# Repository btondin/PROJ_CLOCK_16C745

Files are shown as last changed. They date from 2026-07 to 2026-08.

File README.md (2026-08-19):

# VFDCLK — Relógio VFD com PIC16C745

Relógio e termo-higrômetro de bancada baseado no microcontrolador
**PIC16C745** (USB 1.1 nativo). Mostra num display **VFD IEE Century 036X2
(20×2)** a **hora e a data**, alternando com **temperatura e umidade**, e
**acerta o relógio pela porta USB**: basta conectar o dispositivo ao PC e
rodar um pequeno utilitário em Python que envia a hora local — sem
instalar driver (o aparelho enumera como HID genérico).

> Firmware em C (MPLAB XC8), escrito na forma canônica de projetos para
> PIC: `board.h` central, um driver por periférico, documentação e
> referência de datasheet em cada módulo. Compila em **90,6 %** da ROM
> (7423/8192 words) e **96,9 %** da RAM (248/256 bytes) do PIC16C745.

---

## Recursos

- ⏰ **Relógio/calendário** com RTC **DS3231** (±2 ppm, com bateria de
  retenção). Detecta hora inválida (flag OSF) e avisa no display.
- 🌡️ **Temperatura e umidade** com sensor **Sensirion SHT15**, incluindo
  verificação de **CRC-8** e conversão em **ponto fixo** (sem `float`,
  validada contra as fórmulas oficiais da Sensirion).
- 🖥️ **Display VFD 20×2** em modo serial (19200 8N1). A **linha de cima
  é fixa com o horário** e o indicador de alarme; só a **linha de baixo
  alterna** (6 s data / 4 s clima):

  ```
  |      14:35:27     S|      S = sino, só com o alarme ligado
  |   TER 16/07/2026   |   <-> | 23.4 °C     45.2 %RH|
  ```

  As duas linhas são escritas num único fluxo de 40 caracteres
  (auto-wrap), o que mantém a 2ª linha estável sem depender do comando
  de trava de rolagem. Como o relógio fica sempre na mesma posição, a
  atualização por segundo reescreve só o dígito que mudou — sem piscar, e
  isso vale nas duas telas do carrossel.
- 🔔 **Os dois símbolos vêm por caminhos diferentes**:
  - o **grau** é caractere **nativo** da fonte deste módulo (`B9h`), então
    não gasta comando nem slot;
  - o **sino** não existe na fonte, então é desenhado numa matriz 5×7 e
    gravado no charset (`F6h`, comando `18h`) uma vez no boot.
- 🔌 **Acerto de hora por USB** (classe HID, **sem driver**): o firmware
  recebe a hora do PC e grava no DS3231. Todo o stack USB roda por
  interrupção, então o relógio nunca "trava" durante a comunicação.
- ⏱️ **Alarme de despertador, só em DIA ÚTIL** (seg–sex), fixo: é o uso
  real do aparelho e o espaço de programa é curto, então não há opção de
  menu para isso. O horário é configurável pelo PC (`--alarme 07:30`) e
  liga/desliga pelos botões; tudo mora nos registradores do **DS3231
  alimentados pela bateria** — a única memória não-volátil do projeto, já
  que o PIC16C745 é OTP e **não tem EEPROM**. Aviso sonoro (buzzer) +
  mensagem piscando no display; ao tocar, **qualquer botão silencia** (e
  rearma para o dia seguinte).

  > O filtro de dia útil é feito pelo firmware: o DS3231 só sabe casar
  > *um* dia da semana específico, não "seg a sex". Ele dispara todo dia
  > e o firmware, no fim de semana, reconhece o flag em silêncio.

  Ligado ou desligado aparece direto na tela do relógio, na última coluna
  da linha de cima: **sino** ou **nada**.
- 🔘 **Menu de configuração por dois botões**: o **botão 1** abre o menu e
  percorre as opções (**alarme**, **brilho da tela**); o **botão 2** altera
  a opção mostrada — o alarme liga/desliga, e o brilho sobe até o máximo e
  volta ao mínimo. Sem toque por 3 s, o menu fecha e o carrossel volta.
- 🐕 **Watchdog ligado** (~2,3 s): qualquer travamento reinicia o PIC e o
  relógio se recupera sozinho, em vez de ficar mudo. As esperas longas do
  boot são fatiadas com `CLRWDT` (macro `ESPERAR_MS`, em `board.h`), porque
  o pior caso do temporizador do 16C745 é ~0,9 s, não os 2,3 s nominais.
- 💓 **LED de heartbeat** (RA2): pisca a ~1 Hz enquanto o laço roda —
  sinal permanente de que o PIC está vivo, e um diagnóstico grátis (se
  congelar, algo travou). Fica em RA2 (não em RC0) porque o RC0 é o pino
  do Timer1, usado como base de tempo do bipe do alarme.

---

## Estrutura do repositório

```
PROJ_CLOCK_16C745/
├── README.md                 ← este arquivo
├── LICENSE                   ← MIT (código)
├── VFDCLK.X/                 ← projeto MPLAB X (firmware)
│   ├── main.c                ← laço principal e telas
│   ├── board.h               ← mapa de pinos e macros de hardware
│   ├── uart.c/.h             ← USART (serial para o VFD)
│   ├── vfd.c/.h              ← driver do display IEE 036X2
│   ├── swi2c.c/.h            ← mestre I²C por software
│   ├── ds3231.c/.h           ← driver do RTC
│   ├── sht1x.c/.h            ← driver do sensor + conversão ponto fixo
│   ├── usb_hid.c/.h          ← stack USB HID (capítulo 9 + classe)
│   ├── usb_desc.c/.h         ← descritores USB
│   └── botoes.c/.h           ← debounce e toque curto/longo
├── DTCAPP/                   ← utilitário do PC (Python)
│   ├── dtc_sync.py           ← acerta hora e alarme pelo USB
│   ├── teste_conversao.py    ← valida a matemática do SHT15
│   └── requirements.txt
├── HARDWARE/
│   ├── pinagem.md            ← ligação elétrica completa (LEIA-ME)
│   └── VFD_CLOCK.pdsprj      ← simulação em Proteus
└── DOCS/                     ← datasheets (fora do controle de versão)
```

> A pasta `DOCS/` fica **fora do Git** (ver `.gitignore`): o datasheet do
> display IEE é material proprietário e não pode ser redistribuído. Os
> links oficiais estão [na seção de referências](#referências-datasheets).

---

## Hardware

Resumo dos periféricos (detalhes, valores de componentes e esquemático em
[`HARDWARE/pinagem.md`](HARDWARE/pinagem.md)):

| Bloco | Pinos do PIC | Observação |
|---|---|---|
| Display VFD  | RC6/TX (17) | serial 19200 8N1, **via MAX232** |
| RTC DS3231 | RB4/SCL, RB5/SDA, RB0/INT | I²C por software (pull-ups 4,7 kΩ); INT/SQW no INT0 (uso futuro) |
| Sensor SHT15 | RB2/DATA, RB3/SCK | Sensibus, pull-up 10 kΩ em DATA |
| USB | RC4/D-, RC5/D+, VUSB | low-speed, 1,5 kΩ de VUSB para D- |
| Clock | OSC1/OSC2 (9/10) | cristal 24 MHz (HS, sem PLL) |
| Botões | RA0, RA1 (2/3) | menu: navegar / alterar, pull-up 10 kΩ |
| Buzzer | RC2 (13) | alarme, via transistor NPN |
| LED heartbeat| RA2 (4) | liveness ~1 Hz, série c/ 330 Ω |
| Base de tempo| TMR1 (usa RC0) | ritmo do bipe; RC0 fica sem uso externo  |

⚠️ **Ponto de atenção — serial do display:** o VFD espera a linha em
repouso no nível **baixo** (mark, padrão EIA-232), enquanto a UART do PIC
repousa em nível **alto**. Um **MAX232** entre RC6 (T1IN) e a entrada do
display (T1OUT) faz as duas coisas: converte TTL ↔ EIA-232 e inverte a
polaridade. O esquemático completo (canal, capacitores e jumpers do
display) está no documento de hardware.

---

## Compilando o firmware

**Ferramentas** (as mesmas com que o projeto foi validado):

- MPLAB X IDE **v6.30**
- Compilador MPLAB **XC8 v4.00**
- Device Family Pack **PIC12-16Cxxx_DFP 1.7.175**

### Pelo MPLAB X (recomendado)

1. `File → Open Project…` e selecione a pasta `VFDCLK.X`.
2. Clique em **Build** (o martelo). O `.hex` sai em
   `VFDCLK.X/dist/default/production/VFDCLK.X.production.hex`.

### Pela linha de comando

```bash
cd VFDCLK.X
make            # usa os Makefiles do projeto + XC8
```

> É esperado o build emitir avisos `(520) function ... is never called`
> para algumas funções de API dos drivers (ex.: `vfd_limpar`,
> `uart_enviar`): elas fazem parte da biblioteca reutilizável de cada
> módulo, não são usadas por *este* programa e o XC8 as remove do binário
> (garbage collection). O advisory `(1510)` sobre `ep1_armar` também é
> normal — o compilador duplica a função por ela ser chamada tanto pelo
> laço quanto pela interrupção.

### Gravando o PIC16C745

O PIC16C745 é **OTP** (memória EPROM). Para desenvolvimento, use a versão
**/JW** (com janela de quartzo, apagável por UV) e um gravador compatível
(ex.: PICSTART/PICkit com adaptador). Grave o `.hex` gerado acima. Os bits
de configuração já vão embutidos (`FOSC=HS, WDTE=ON, PWRTE=ON, CP=OFF`).

---

## Acertando a hora pelo USB

Com o relógio conectado ao PC (ele aparece como HID, sem driver):

```bash
cd DTCAPP
pip install -r requirements.txt
python dtc_sync.py         # usa a hora deste PC
python dtc_sync.py --ntp   # usa a hora oficial, buscada na internet
```

O utilitário envia a hora local; o firmware grava no DS3231, o display
mostra **"HORA SINCRONIZADA"** e o script lê de volta hora, temperatura
e umidade como confirmação.

Com **`--ntp`** ele consulta antes um servidor de tempo por **SNTP**
(RFC 4330, UDP 123 — padrão `a.ntp.br`/`b.ntp.br` do NIC.br, com
`pool.ntp.org` de reserva; trocável por `--ntp-servidor`). O SNTP mede o
tempo de ida-e-volta do pacote e desconta metade dele, acertando em
milissegundos — muito além do que um RTC de 1 s de resolução precisa, e
melhor que uma API HTTP, cuja latência de requisição vai embutida na
resposta. Não custa dependência nenhuma: só `socket` e `struct` da
biblioteca padrão. O envio é alinhado com a virada do segundo *já
corrigido*, então o DS3231 começa o segundo junto com a fonte oficial.

> O NTP entrega tempo absoluto (UTC); o **fuso** continua vindo da
> configuração do PC. Ou seja: `--ntp` conserta relógio atrasado, não
> fuso horário errado.

No Windows, [`DTCAPP/configurar.bat`](DTCAPP/configurar.bat) dá um menu
(duplo-clique) para sincronizar a hora e configurar o alarme sem digitar
comando nenhum. Detalhes em [`DTCAPP/README.md`](DTCAPP/README.md).

---

## Como funciona (visão geral)

- **Laço principal cooperativo** (`main.c`): a cada ~50 ms lê o DS3231;
  na virada do segundo, redesenha a tela, alterna a linha de baixo entre
  data e clima e, a cada 30 s, dispara uma medição do SHT15. Alimenta o
  watchdog uma vez por volta.
- **USB por interrupção** (`usb_hid.c`): o SIE do PIC16C745 cuida da
  camada física; o firmware trata apenas transações completas (reset,
  enumeração do capítulo 9, classe HID). A troca de dados usa dois
  "correios" protegidos contra concorrência entre a ISR e o laço.
- **Sem `float`**: a conversão do SHT15 usa inteiros de 32 bits com
  coeficientes escalonados; o erro versus as fórmulas oficiais é
  < 0,05 °C / 0,15 %RH, comprovado por `DTCAPP/teste_conversao.py`.
- **Pilha de hardware de 8 níveis**: é o recurso mais escasso do projeto e
  a origem do bug mais difícil que ele teve. Ela é **circular e não detecta
  estouro**: passando de 8, o endereço de retorno mais antigo é sobrescrito
  em silêncio e o PIC volta para lixo. Com `_main` exigindo 8 e a ISR do USB
  exigindo 3, bastava a interrupção cair no ponto mais fundo para o firmware
  sumir — sem display e sem heartbeat. Como depende do instante da
  interrupção, o defeito era uma **corrida**: builds quase idênticos ora
  rodavam, ora não.

  A cadeia foi encurtada para **7 de 8** eliminando chamadas escondidas de
  biblioteca no caminho mais fundo: divisões e multiplicações em `por_decimos`
  e `vfd_campo_bcd` (que viravam `___lwdiv`/`___lwmod`/`___bmul`) e funções
  intermediárias de uma linha só. Confira o orçamento sempre que mexer no
  código, com:

  ```bash
  grep -B2 "Hardware stack levels required" VFDCLK.X/dist/default/production/VFDCLK.X.production.lst
  ```

  Se `_main` voltar a 8, o firmware pode parar de dar boot sem nenhuma outra
  pista. Os módulos são deliberadamente "achatados" por esse motivo — ver
  também a nota no cabeçalho de `usb_hid.c`.

---

## Referências (datasheets)

Documentos oficiais usados no projeto (baixe direto do fabricante):

- **PIC16C745/765** — Microchip, doc. *DS41124* →
  <https://www.microchip.com/en-us/product/PIC16C745>
- **DS3231** — Analog Devices (Maxim) →
  <https://www.analog.com/en/products/ds3231.html>
- **SHT1x / SHT15** — Sensirion (datasheet, *Sample Code* e *CRC
  Calculation*) →
  <https://sensirion.com/products/catalog/SHT15>
- **Display VFD IEE Century 036X2** — Industrial Electronic Engineers,
  *Product Specification S036X2* (documento proprietário; solicite ao
  fabricante) → <https://www.ieeinc.com/>

---

## Nota sobre o VID/PID USB

O firmware usa o par de **teste** do projeto [pid.codes](https://pid.codes)
(**VID 0x1209 / PID 0x0001**), adequado para desenvolvimento e uso
pessoal. Para distribuir um produto, solicite um PID próprio — nunca
reutilize o VID/PID de outro fabricante.

---

## Licença

Código sob licença **MIT** (ver [LICENSE](LICENSE)). A licença cobre o
firmware e o utilitário do PC; **não** se estende aos datasheets dos
fabricantes nem ao protocolo proprietário do display IEE.

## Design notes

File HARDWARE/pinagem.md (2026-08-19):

11não# Hardware — Relógio VFD (PIC16C745)

Documento de ligação elétrica do projeto. A pinagem do MCU foi conferida
contra o arquivo de definição oficial do dispositivo (Microchip DFP
`PIC16C745.PIC`) e o datasheet DS41124D.

> A simulação em Proteus está em [`VFD_CLOCK.pdsprj`](VFD_CLOCK.pdsprj)
> (abrir com o Proteus 8). Ela reproduz a fiação descrita abaixo.

---

## 1. Pinagem do PIC16C745 (encapsulamento DIP-28 / SOIC-28)

```
                    ┌───────────────┐
        MCLR/VPP  1 ┤●              ├ 28  RB7/ICSPDAT
         RA0/AN0  2 ┤ ── BOTÃO 1    ├ 27  RB6/ICSPCLK
         RA1/AN1  3 ┤ ── BOTÃO 2    ├ 26  RB5   ── SDA  (DS3231)
         RA2/AN2  4 ┤ ── LED (HB)   ├ 25  RB4   ── SCL  (DS3231)
    RA3/AN3/VREF  5 ┤               ├ 24  RB3   ── SCK  (SHT15)
     RA4/T0CKI    6 ┤               ├ 23  RB2   ── DATA (SHT15)
        RA5/AN4   7 ┤   PIC16C745   ├ 22  RB1   (livre)
            VSS   8 ┤   (GND)       ├ 21  RB0   ── INT/SQW (DS3231)
      OSC1/CLKIN  9 ┤   ── xtal     ├ 20  VDD   (+5 V)
     OSC2/CLKOUT 10 ┤   ── xtal     ├ 19  VSS   (GND)
   RC0/T1OSO     11 ┤ (TMR1, livre) ├ 18  RC7/RX/DT
   RC1/T1OSI     12 ┤               ├ 17  RC6/TX ── serial p/ VFD (via MAX232)
      RC2/CCP1   13 ┤ ── BUZZER     ├ 16  RC5/D+ ── USB D+
           VUSB  14 ┤               ├ 15  RC4/D- ── USB D-
                    └───────────────┘
```

| Pino | Sinal | Ligação no projeto |
|-----:|---|---|
| 1  | MCLR/VPP | Pull-up 10 kΩ para +5 V (+ conector ICSP p/ gravar) |
| 2  | RA0 | **Botão 1** (navegar no menu) — p/ GND, pull-up 10 kΩ |
| 3  | RA1 | **Botão 2** (alterar opção) — p/ GND, pull-up 10 kΩ |
| 4  | RA2 | **LED de heartbeat** — em série c/ ~330 Ω para GND |
|  11  | RC0 | **Sem ligação externa** — é T1OSO/T1CKI, usado pelo TMR1 internamente (base de tempo do bipe do alarme); não usar como I/O |
|  13  | RC2 | **Buzzer** via transistor NPN (nível 1 = tocando) |
| 8  | VSS | GND |
| 9  | OSC1 | Cristal 24 MHz + 15–22 pF para GND |
|  10  | OSC2 | Cristal 24 MHz + 15–22 pF para GND |
|  14  | VUSB | Capacitor de 0,22 µF para GND; **1,5 kΩ p/ D‑ (pino 15)** |
|  15  | RC4/D- | USB D- (verde) |
|  16  | RC5/D+ | USB D+ (branco) |
|  17  | RC6/TX | Entrada serial do VFD (J1-14) **via MAX232** (T1IN, pino 11)  |
|  19  | VSS | GND |
|  20  | VDD | +5 V |
|  21  | RB0/INT | **INT/SQW do DS3231** (dreno aberto, pull-up 4,7 kΩ; entrada INT0 — **uso futuro**) |
|  22  | RB1 | Livre |
|  23  | RB2/DATA | DATA do SHT15 (pull-up 10 kΩ para +5 V) |
|  24  | RB3/SCK | SCK do SHT15 |
|  25  | RB4/SCL | SCL do DS3231 (pull-up 4,7 kΩ para +5 V) |
|  26  | RB5/SDA | SDA do DS3231 (pull-up 4,7 kΩ para +5 V) |
| 27/28| RB6/RB7 | ICSPCLK/ICSPDAT (gravação in-circuit) |

O pino RB1 fica livre (RB6/RB7 são reservados ao ICSP de gravação).

---

## 2. Alimentação e oscilador

- **+5 V / GND**: VDD no pino 20, VSS nos pinos 8 e 19 (ligar ambos!).
  Capacitor de desacoplamento de 100 nF junto a cada par VDD/VSS.
- **Cristal**: 24 MHz entre OSC1 (9) e OSC2 (10), com dois capacitores de
  carga (15–22 pF) de cada pino para GND, em modo HS (bit de configuração
  `FOSC = HS`). Os 24 MHz são exigidos diretamente pelo USB (sem PLL).
  Não use ressonador de baixa precisão: o USB exige ±0,25 % de tolerância.

---

## 3. USB (low-speed)

O PIC16C745 tem transceptor e regulador de 3,3 V embutidos.

```
   Conector USB          PIC16C745
   ─────────────         ─────────────
   VBUS (+5V) ───────────► VDD (20)   (se alimentado pelo barramento)
   D-         ───────────► RC4/D- (15)
   D+         ───────────► RC5/D+ (16)
   GND        ───────────► VSS (8,19)

   VUSB (14) ──┬── 0,22 µF ── GND
               └── 1,5 kΩ ──► D- (15)     ◄── identifica LOW-SPEED
```

- O resistor de **1,5 kΩ de VUSB (3,3 V) para D‑** é o que faz o host
  reconhecer um dispositivo **low-speed** (o firmware liga o VUSB via
  `UCTRL.DEV_ATT` em `usb_iniciar()`).
- Alimentação: o projeto declara-se **self-powered** (descritor,
  `bMaxPower = 20 mA`). Se preferir alimentar pelo próprio USB
  (bus-powered), ligue VBUS ao VDD e troque `bmAttributes` para 0x80 no
  `usb_desc.c` — mas cuidado com o limite de corrente do VFD (o display
  consome bem mais que 100 mA e deve ter fonte própria de qualquer modo).

---

## 4. Serial para o display VFD (o ponto que exige atenção)

O display **IEE 036X2** é usado em **modo serial** (19200 8N1). Ajuste os
jumpers de "personalidade" da placa do display para **19200 baud** e
partida **NORM**, mantendo o **conjunto de comandos nativo (Intel, que é o
padrão)** — **não** selecione o modo **LCD** (ele troca os comandos para os
do HD44780, e o firmware usa os códigos nativos IEE). Seção 3.2.3 do
datasheet do display.

### Por que um MAX232 (conversão de nível + inversão de polaridade)

O datasheet do display (seção 3.2.2.1) especifica a entrada serial em
níveis **EIA-232**, com a linha em **repouso no nível baixo (mark)**:

| Nível lógico | Tensão EIA-232 | Estado de repouso |
|---|---|---|
| space (logic 0 / start) | +3 a +15 V | |
| mark  (logic 1 / idle) | −3 a −15 V | **repouso = mark**|

A UART do PIC (RC6/TX) faz o oposto: repousa em **nível alto** (idle = 5 V)
e o PIC16C745 **não** inverte por hardware. O **MAX232 resolve as duas
coisas ao mesmo tempo**, pois é um driver **inversor** *e* conversor de
nível:

- converte TTL (0/5 V) → EIA-232 real (±~8 V); e
- inverte a polaridade que o display espera:
  - RC6 em repouso **alto** (mark)  → T1OUT **negativo** = mark ✔
  - RC6 em **start** baixo (space)  → T1OUT **positivo** = space ✔

Como só transmitimos para o display, usa-se **um único canal (T1)**:

```
   PIC RC6/TX (17) ──► T1IN (11)   MAX232   T1OUT (14) ──► J1-14 (SERIAL INPUT do VFD)
                       VCC (16) = +5 V      GND (15) = GND comum (PIC + display)

   Capacitores de charge-pump — 0,1 µF cerâmicos (SP232A / MAX232A):
     C1: pino 1 (C1+) ↔ pino 3 (C1−)       C2: pino 4 (C2+) ↔ pino 5 (C2−)
     V+ (pino 2) ── C ── GND               V− (pino 6) ── C ── GND
     + 100 nF de VCC (16) para GND (desacoplamento)
   Confira os valores exatos dos capacitores no datasheet do seu MAX232.
```

**Pinos não usados (canais R1, R2 e T2):**

| Pino | Nome | O que fazer |
|---:|---|---|
| 10 | T2IN | **ligar ao GND** — é a única entrada TTL sobrando |
| 7 | T2OUT | deixar **aberto** (saída) |
| 9 | R2OUT | deixar **aberto** (saída) |
| 12 | R1OUT | deixar **aberto** (saída) |
| 8 | R2IN | deixar **aberto** |
| 13 | R1IN | deixar **aberto** |

Regra geral: **saída nunca se amarra** (ligá-la a GND/VCC é curto);
**entrada não pode ficar indefinida**. Nesta família as entradas já têm
resistor interno — TTL com pull-up de ~400 kΩ e RS-232 com pull-down de
~5 kΩ — então nada flutua de fato. Mesmo assim vale aterrar o T2IN: o
pull-up de 400 kΩ é fraco e um fio solto em protoboard capta ruído.

- O firmware (`uart.c`) transmite UART padrão: toda a conversão de nível e
  a inversão de polaridade acontecem no MAX232, de forma transparente ao
  código.
- GND do PIC, do MAX232 e do display **sempre** em comum.

---

## 5. Barramentos dos periféricos

### DS3231 (I²C por software) — RB4/RB5 + INT/SQW em RB0

```
   +5 V ──4,7kΩ──┬───────────────────── SCL     (RB4, pino 25)
   +5 V ──4,7kΩ──┼──┬────────────────── SDA     (RB5, pino 26)
   +5 V ──4,7kΩ──┼──┼──┬─────────────── INT/SQW (RB0/INT, pino 21)
                 │  │  │
              ┌──┴──┴──┴──┐
              │  DS3231   │  VBAT ── bateria CR2032 (+)
              └───────────┘  GND  ── GND
```
Endereço I²C fixo 0x68. A bateria mantém a hora com a alimentação
principal desligada.

O **INT/SQW** é uma saída de **dreno aberto** (exige o pull-up externo,
que pode ir a uma alimentação de até **5,5 V**, independente de VCC) e
liga ao **RB0/INT** — a entrada de interrupção externa **INT0** do PIC.
Hoje o firmware **não** o utiliza (o alarme é lido por *polling* do flag
`A1F`, que é *latched*), mas o pino fica reservado para, no futuro,
disparar por interrupção de borda: com `INTCN=1` (padrão no power-on) a
saída é o **alarme ativo-baixo**; com `INTCN=0` vira **onda quadrada**
(frequência por RS2:RS1). Ver [`board.h`](../VFDCLK.X/board.h)
(`DS3231_INT_MASCARA`).

### SHT15 (Sensibus — 2 fios proprietário Sensirion) — RB2/RB3

```
   +5 V ──10kΩ──── DATA (RB2, pino 23)
                   SCK  (RB3, pino 24)  ── direto (só o PIC gera clock)
```
O pull-up de 10 kΩ em DATA é exigência do protocolo (a linha é
bidirecional; o sensor a puxa para 0 nos ACKs e ao final da medição).
Coloque 100 nF entre VDD e GND do sensor, bem próximo dele.

---

## 5.1 Botões e buzzer (alarme)

Os botões ficam no **PORTA** de propósito: o PORTB é reservado aos dois
barramentos bit-bang (I²C e Sensibus), e mantê-lo livre de outras
escritas evita qualquer interferência de *read-modify-write*.

```
   +5 V ──10kΩ──┬── RA0 (pino 2)         +5 V ──10kΩ──┬── RA1 (pino 3)
                │                                      │
             [BOTÃO 1]                              [BOTÃO 2]
                │                                      │
               GND                                    GND
```

| Botão | Ação |
|---|---|
| **1** (RA0) | **NAVEGAR**: abre o menu de configuração e percorre as opções (ALARME, BRILHO) |
| **2** (RA1) | **ALTERAR**: muda o valor da opção mostrada. No **alarme**, liga/desliga (o disparo é sempre só em dia útil, seg-sex, fixo no firmware). No **brilho**, sobe até o máximo e volta ao mínimo |

O estado do alarme também fica visível na tela do relógio, nas duas
últimas colunas da linha de cima: nada (desligado), **sino** (todos os
dias) ou **`U`+sino** (só dias úteis).

Com o alarme **tocando**, qualquer toque em qualquer botão silencia (e rearma
para o dia seguinte) — a distinção curto/longo continua disponível no driver
(`botoes.c`) para uso futuro, mas hoje qualquer toque conta como um "clique".

Buzzer: **TMB-05** — buzzer **magnético ativo** de 5 V (tem oscilador
interno, então emite som só com nível DC; o firmware apenas liga/desliga
o pino RC2, sem PWM). É acionado por um transistor porque o pino do PIC
não deve fornecer a corrente dele diretamente, e leva um **diodo de
roda-livre** por ser uma carga indutiva (magnética):

```
                          +5 V
                           │
                 ┌─────────┼─────────┐
                 │         │          │
              [diodo]  [TMB-05]       │   diodo 1N4148/1N4007
              catodo──►  buzzer       │   catodo (faixa) p/ +5 V
                 │         │          │
                 └─────────┴──► C     │
   RC2 (13) ──[1 kΩ]──B┤ NPN (BC547 / 2N3904)
                        └E── GND
```

- O **diodo em paralelo com o buzzer** (catodo (faixa) no +5 V, anodo no
  coletor) absorve o pico de tensão quando o transistor corta — sem ele,
  a indutância do TMB-05 pode danificar o transistor com o tempo.
- Corrente típica do TMB-05 ≈ 25–35 mA @ 5 V, folgada para um BC547
  (Ic máx 100 mA); a base com 1 kΩ dá saturação de sobra.
- O RC2 é o **CCP1**: um dia, se trocar por um piezo *passivo*, dá para
  gerar o tom por PWM (exigiria mudar o firmware, que hoje só chaveia o
  pino).

> **Nota sobre o pino INT/SQW do DS3231:** ele é ligado ao **RB0/INT**
> (entrada de interrupção externa INT0), com pull-up externo, e fica
> **reservado para uso futuro**. O firmware atual **ainda não o utiliza**:
> o flag de alarme `A1F` (status `0Fh`) é *latched* — fica em 1 até ser
> reconhecido — então o alarme é lido por *polling* 1×/segundo, sem risco
> de perder um disparo. Com o INT/SQW já roteado até o RB0/INT, dá para
> migrar esse polling para interrupção por borda quando quiser (INT0:
> `INTEDG=0`, `INTE=1`, tratar `INTF` na ISR). Ver [`board.h`](../VFDCLK.X/board.h).

### LED de heartbeat (liveness) — RA2

Item **fixo** do projeto: um LED que pisca a ~1 Hz sempre que o firmware
está executando o laço principal. Serve como sinal permanente de que o
PIC está vivo e o laço rodando — se ele congelar, algo travou (ex.: I²C
preso). Também facilita o diagnóstico na bancada: display apagado **com**
o LED piscando aponta problema no caminho do display, não no processador.

```
   RA2 (4) ──►|──[ ~330 Ω ]── GND     (acende em nível alto)
             LED
```

O firmware pisca o LED na cadência do laço (contador ÷10 sobre os 50 ms),
então o ritmo do pisca também reflete a saúde/tempo do laço.

> **Por que RA2 e não RC0:** o RC0 é também o pino T1OSO/T1CKI do Timer1,
> usado internamente como base de tempo do bipe do alarme (ver firmware).
> Em bancada, ligar o TMR1 fez o LED parar de acender quando estava em
> RC0, mesmo com o oscilador do timer desligado (clock interno) — por
> isso o LED foi para RA2, um pino puramente digital sem função de
> periférico associada.

---

## 6. Lista de materiais (resumo)

| Qtd | Componente | Observação |
|----:|---|---|
| 1 | PIC16C745 (DIP-28) | versão **/JW** (janela) p/ regravar |
| 1 | Display VFD IEE 036X2 (20×2) | jumper em 19200 baud |
| 1 | DS3231 (módulo com bateria) | RTC I²C |
| 1 | Sensirion SHT15 | sensor T/RH |
| 1 | Cristal 24 MHz + 2× 15–22 pF | clock do USB |
| 1 | SP232ACP (Sipex; equiv. MAX232A) | conversor de nível serial TTL↔EIA-232 |
| 5 | Capacitor 0,1 µF cerâmico | charge-pump do SP232ACP |
| 2 | Resistor 4,7 kΩ | pull-ups I²C (SDA/SCL) |
| 1 | Resistor 4,7 kΩ | pull-up do INT/SQW (RB0/INT) |
| 1 | Resistor 10 kΩ | pull-up DATA do SHT15 |
| 1 | Resistor 10 kΩ | pull-up de MCLR |
| 2 | Botão táctil (push-button) | troca de tela / alarme |
| 2 | Resistor 10 kΩ | pull-ups dos botões |
| 1 | Buzzer ativo 5 V (TMB-05) | alarme sonoro |
| 1 | Transistor NPN (BC547/2N3904) | aciona o buzzer |
| 1 | Resistor 1 kΩ | base do transistor do buzzer |
| 1 | Diodo 1N4148/1N4007 | roda-livre do buzzer |
| 1 | LED (qualquer cor) | heartbeat / liveness (RA2) |
| 1 | Resistor 330 Ω | limitador do LED de heartbeat |
| 1 | Resistor 1,5 kΩ | identificação USB low-speed |
| 1 | Capacitor 0,22 µF | VUSB |
| — | Capacitores 100 nF | desacoplamento (1 por CI) |
| 1 | Conector USB tipo B (ou cabo) | — |

> **Nota sobre o PIC16C745:** é uma peça **OTP** (EPROM). Para
> desenvolvimento, use a versão **/JW** com janela de quartzo, apagável
> por UV — assim você regrava durante os testes. Grave com o `.hex` gerado
> em `VFDCLK.X/dist/default/production/`.

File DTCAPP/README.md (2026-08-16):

# DTCAPP — utilitário de sincronização do relógio VFD

Ferramenta **manual** (sem serviço em segundo plano): rode quando quiser
acertar o relógio pela hora do PC.

## Instalação

Requer Python 3.8+ ([python.org](https://www.python.org/downloads/)) e a
biblioteca `hidapi`:

```
pip install -r requirements.txt
```

## Uso

Conecte o relógio VFD numa porta USB (ele enumera como dispositivo HID,
sem precisar de driver).

### Pelo menu (`configurar.bat`) — mais fácil

Dê duplo-clique em [`configurar.bat`](configurar.bat). Ele confere se o
Python e a `hidapi` estão instalados (oferece instalar sozinho se
faltar) e mostra um menu com as mesmas ações de baixo, sem precisar
decorar parâmetros de linha de comando. A opção **1** sincroniza pela
internet (mais preciso) e a **2** pela hora do próprio PC.

### Pela linha de comando

```
python dtc_sync.py                 # sincroniza com a hora deste PC (padrão)
python dtc_sync.py --ntp           # sincroniza com a hora oficial (internet)
python dtc_sync.py --status        # só mostra o estado, sem alterar
python dtc_sync.py --alarme 07:30  # programa o alarme diário e liga
python dtc_sync.py --alarme on     # liga o alarme (mantém o horário)
python dtc_sync.py --alarme off    # desliga o alarme
```

Ao sincronizar, o script envia a hora local, o firmware grava no DS3231
e o display mostra "HORA SINCRONIZADA". Em seguida ele lê de volta a
hora, temperatura, umidade e o estado do alarme como confirmação.

### Hora pela internet (`--ntp`)

Sem a opção, o script confia no relógio do PC — que costuma ter alguns
segundos de erro (e às vezes bem mais). Com `--ntp`, ele consulta um
servidor de tempo antes de enviar:

```
python dtc_sync.py --ntp                       # servidores padrão
python dtc_sync.py --ntp-servidor ntp.empresa  # servidor específico
```

Saída típica:

```
Consultando servidor de tempo a.ntp.br ...
  respondeu (stratum 2, ida-e-volta 28 ms)
  relógio do PC está 50.8 s adiantado — será corrigido no envio
Hora enviada ao relógio: Sunday 16/08/2026 14:58:50  (fonte: NTP a.ntp.br)
```

Detalhes que valem saber:

- **É SNTP (RFC 4330), não uma API HTTP.** O SNTP mede o tempo de
  ida-e-volta do pacote e desconta metade dele; num `GET` HTTP a
  latência da requisição vai embutida na resposta, sem como descontar.
  Resultado: erro de milissegundos, folgadíssimo para um RTC de 1 s de
  resolução.
- **Não instala nada.** Usa só `socket` e `struct` da biblioteca padrão
  — o `requirements.txt` continua com a `hidapi` e mais nada.
- **Servidores padrão:** `a.ntp.br`, `b.ntp.br` (NTP.br/NIC.br, hora
  legal brasileira) e `pool.ntp.org` de reserva, tentados nessa ordem.
- **Fuso horário continua vindo do PC.** O NTP entrega tempo absoluto
  (UTC); a conversão para a hora local que o DS3231 guarda usa o fuso do
  Windows. NTP conserta relógio atrasado, **não** fuso configurado
  errado.
- **Falhou a rede, ninguém acerta nada.** Se nenhum servidor responder,
  o script sai com código 6 sem tocar no relógio, em vez de cair
  silenciosamente para a hora do PC (que é justamente o que você quis
  evitar ao pedir `--ntp`). Algumas redes corporativas bloqueiam a UDP
  123 — nesse caso, aponte `--ntp-servidor` para o servidor de tempo
  interno, ou rode sem `--ntp`.

**O alarme fica guardado no próprio DS3231** (registradores alimentados
pela bateria), então sobrevive a quedas de energia — o PIC16C745 é OTP e
não tem EEPROM onde guardar configuração.

Também dá para operar o alarme pelos **botões** do aparelho: o botão 1
abre o menu de configuração (ALARME/BRILHO) e o botão 2 altera a opção
mostrada — liga/desliga o alarme, por exemplo. Com o alarme tocando,
qualquer botão silencia.

Códigos de saída: `0` sucesso · `1` dispositivo não encontrado ·
`2` falta a biblioteca `hid` · `3/4` falha na comunicação ·
`5` horário de alarme inválido · `6` não obteve a hora da internet.

> **Windows:** se `python` abrir a Microsoft Store, use o caminho
> completo do interpretador, por exemplo
> `& "$env:LOCALAPPDATA\Programs\Python\Python312\python.exe" dtc_sync.py`,
> ou desative os *aliases de execução* em Configurações → Aplicativos.
> Rode `chcp 65001` antes para os acentos aparecerem corretamente.

## teste_conversao.py

Teste de engenharia (não é preciso rodar para usar o relógio): valida a
aritmética de ponto fixo do firmware (`VFDCLK.X/sht1x.c`) contra as
fórmulas float oficiais da Sensirion, em toda a faixa do sensor:

```
python teste_conversao.py
```

Aprovação: erro ≤ 0,06 °C e ≤ 0,20 %RH em relação às fórmulas oficiais.

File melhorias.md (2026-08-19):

# Melhorias — VFDCLK

Lista de melhorias observadas em bancada. Os 6 itens foram **implementados**
(build de 22/07/2026, ROM 90,6% / RAM 89,8%) e aguardam validação no hardware.
Cada item mantém o sintoma e o diagnóstico como registro, seguidos de uma nota
**Feito:** com o que foi alterado.

Status:
- ✅ **#1** Dois-pontos na virada de minuto — redesenho completo quando muda min/hora.
- ✅ **#2** Bipe irregular — base de tempo real por TMR1 + SHT adiado no alarme.
  O TMR1 usa o pino RC0, então o **LED de heartbeat foi movido de RC0 para RA2
  (pino 4)** — com o TMR1 ligado, o RC0 deixava de acionar o LED.
- ✅ **#3** Mensagem do alarme — novo layout + pisca por firmware sincronizado ao bipe.
- ✅ **#4** Menu de brilho travava — respiros no comando multibyte de brilho.
- ✅ **#5** Alarme durante edição — redraw no autossilêncio + fecha o menu ao tocar.
- ✅ **#6** Persistência — brilho salvo nos registradores do Alarme 2 do DS3231.

> Validar no PIC: virada de minuto (#1), bipe+pisca do alarme (#2/#3), ciclar o
> brilho sem travar (#4), alarme por cima do menu (#5), brilho após desligar/
> religar (#6). Se o brilho ainda travar, conferir o LED de heartbeat (RA2):
> piscando = display; congelado = PIC.

---

## 1. Corrupção dos dois-pontos na virada de minuto

**Sintoma:** ao virar de 16:12:59 para 16:13:00, apareceu "16:13000"
(os dois-pontos entre minuto e segundo viraram '0').

**Hipótese:** `tela_hora()` ([main.c](VFDCLK.X/main.c)) faz, na mesma
virada de segundo, DUAS chamadas a `vfd_campo_bcd()`
([vfd.c](VFDCLK.X/vfd.c)) em sequência — uma para minutos (coluna 9) e
outra para segundos (coluna 12) — cada uma com seu próprio comando de
posicionamento (`1Bh`). Em qualquer segundo comum só o campo de
segundos muda (uma chamada); só na virada de minuto é que duas
chamadas de posicionamento saem back-to-back. É bem provável que seja
a mesma classe de problema já visto antes (display "ocupado" após um
`1Bh` e perdendo o byte seguinte) — só que agora entre uma chamada de
`vfd_campo_bcd` e a próxima, sem nenhum atraso extra além do que já
existe dentro de `VFD_IR_PARA`.

**Pista para testar:** forçar esse cenário (dois campos mudando no
mesmo tick) e ver se um pequeno atraso *entre* as duas chamadas de
`vfd_campo_bcd` em `tela_hora()` resolve.

---

## 2. Intervalo do bipe do alarme fica irregular

**Sintoma:** o padrão do buzzer (200 ms ligado / 300 ms desligado)
some vezes fica com intervalos errados — mais visível quando os
segundos "viram" com mais de um dígito mudando. O RTC em si está
correto (o horário não desvia), é só o ritmo sonoro que falha.

**Hipótese (forte):** o contador `buzzer_fase` avança **uma vez por
volta do laço principal** ([main.c](VFDCLK.X/main.c), bloco "0d"),
supondo que cada volta dura sempre ~50 ms (o `__delay_ms(50)` do fim
do laço). Mas a duração da volta NÃO é constante:
- a cada 30 s, `sht1x_medir()` bloqueia ~0,4 s numa única volta;
- os redesenhos do display (principalmente quando mais de um campo
  BCD muda, como no item 1 acima) also alongam aquela volta específica
  com os atrasos de `VFD_IR_PARA`.

Nessas voltas mais longas, `buzzer_fase` avança só 1 passo mesmo com
bem mais tempo real passado — daí o "hiccup" perceptível no ritmo do
bipe, e a correlação com os momentos em que os segundos mostram mais
de um dígito mudando.

**Direção de correção:** desacoplar o ritmo do buzzer da contagem de
voltas do laço — ex.: um contador de tempo real (não incrementado
"por iteração", e sim proporcional ao tempo realmente decorrido), ou
mover o toggle do buzzer para um timer de hardware (TMR0/TMR1),
independente de quanto a volta do laço demorou.

---

## 3. Mensagem do alarme tocando — layout confuso

**Sintoma:** a tela atual (`tela_alarme_tocando()` em
[main.c](VFDCLK.X/main.c)) mostra `***ALARME***` numa linha e
`HH:MM` + `(BTN)` espalhados na outra — informação ruim, ficou
estranho.

**Pedido:** layout mais limpo —
```
ALARME! HH:MM
APERTE QUALQUER BOTAO
```
com o **pisca sincronizado com o bipe** do buzzer.

**Observação importante:** o pisca hoje usa o atributo de hardware do
próprio display (`vfd_quadro_piscante()` em [vfd.c](VFDCLK.X/vfd.c),
comandos `31h`/`32h`) — é um clock **interno ao display**, totalmente
independente do `buzzer_fase` do firmware. Os dois nunca vão ficar de
fato sincronizados desse jeito (frequências geradas por relógios
diferentes). Para sincronizar de verdade, o pisca da linha 1 precisa
virar controlado por firmware (escrever/apagar o texto em sincronia
com o mesmo contador que liga/desliga o buzzer) em vez de usar o
atributo do display. Isso também depende de resolver o item 2 acima
primeiro — sem um `buzzer_fase` com ritmo confiável, sincronizar
qualquer coisa a ele preserva o mesmo defeito.

---

## 4. Menu de brilho trava o aparelho inteiro (precisa desligar/religar)

**Sintoma:** no menu de configuração, opção BRILHO: o primeiro toque
no botão 2 não parece mudar nada visualmente; ao continuar apertando,
em algum nível (relatado no nível 3) o aparelho trava por completo —
só volta ciclando a energia.

Isso é o item **mais sério** da lista (trava total, sem
recuperação — o watchdog está desligado, `WDTE = OFF`). Duas hipóteses,
não excludentes:

**Hipótese A — margem da pilha de hardware (8 níveis) apertada.**
Contei manualmente a profundidade de chamadas no pior caso (ISR de USB
interrompendo bem no meio de `main → tela_config → vfd_quadro`): dá
por volta de 7 dos 8 níveis disponíveis — ficou **muito** perto do
limite, mesmo com `ep0_saida_processar`/`ep0_entrada_processar`
propositalmente "achatados" (ver cabeçalho de
[usb_hid.c](VFDCLK.X/usb_hid.c)). Contagem manual é sujeita a erro
(o compilador pode inlinear ou duplicar funções — já vimos o aviso
`(1510)` sobre `ep1_armar` duplicada). Antes de mexer no código, vale
checar o relatório de call-graph/uso de pilha que o próprio XC8 gera
(`-msummary`, ou o Call Graph do MPLAB X) para um número real em vez
de contagem manual.

**Hipótese B — comando de brilho (`19h 30h FFh nível`) mais lento do
que o assumido.** O driver assume que só `Clear`/`Reset` precisam de
espera explícita (ver cabeçalho de [vfd.h](VFDCLK.X/vfd.h)); o comando
de brilho nunca foi validado contra a tabela de tempos do datasheet
(seção 3.3) — se for uma operação "lenta" como Clear/Reset, mandar o
redesenho da tela (`vfd_quadro`) logo em seguida, sem nenhum atraso
entre os dois, pode confundir o parser do display.

**Primeiro passo de diagnóstico (barato, não precisa mexer em código):**
quando travar de novo, observar se o **LED de heartbeat (RA2) continua
piscando**. Se continuar piscando => o firmware está vivo, o problema é
só no display (aponta para a Hipótese B). Se o LED também congelar =>
o PIC travou de verdade (aponta para a Hipótese A — pilha estourada ou
outro travamento de firmware).

**Feito (Hipótese B confirmada pelo datasheet):** o comando de brilho é
MULTIBYTE (`19h 30h FFh nível`) e a seção 4.1 do datasheet avisa que
*erro em comando multibyte faz o firmware do display "pular" para fora do
modo de controle*. Como `vfd_brilho()` mandava os 4 bytes sem respiro, o
display (ocupado após o código de comando, igual ao caso do `1Bh` de
posição) derrubava um parâmetro; cada toque acumulava a corrupção até
travar o parser. **Correção:** `__delay_ms(VFD_ATRASO_POS_MS)` após o
código de comando e após os parâmetros, em [vfd.c](VFDCLK.X/vfd.c). O PIC
não travava (Hipótese A descartada) — era só o parser do display. Também
documentado que, sem pot. externo no pino DIMMING, o software cobre os 8
níveis (por isso "não mudava" era o 1º comando corrompido, não um limite).

---

## 5. Alarme disparando durante a edição das telas de configuração

**Pedido:** prever o que acontece se o alarme tocar enquanto o menu de
configuração (alarme/brilho) está aberto, e evitar problemas.

**Já está seguro:** o bloco "0a" do laço principal
([main.c](VFDCLK.X/main.c)) intercepta QUALQUER toque de botão
enquanto `alarme_tocando` é verdadeiro e o consome inteiro para
silenciar — os blocos de navegar/alterar do menu ("0b"/"0c") só veem
`btn1`/`btn2` DEPOIS dessa interceptação, já zerados. Ou seja: **não
dá** para acidentalmente mudar o brilho ou o alarme por engano
enquanto o alarme está tocando; o botão sempre silencia primeiro.
A prioridade de desenho de tela (`if (alarme_tocando) {...}`) também já
garante que a tela do alarme toma a frente do menu.

**Lacuna real encontrada:** quando o alarme se autossilencia pelo
tempo de segurança (`ALARME_MAX_SEGUNDOS`, bloco "2b") — ou seja,
ninguém apertou botão — o código zera `alarme_tocando` e força
`tela_desenhada = 0xFFu`, mas **não** liga `redesenhar = true`. Se
`modo_config` estava ativo antes do alarme interromper, o ramo que
prestaria atenção em `tela_desenhada` (o carrossel) nem roda —
quem precisaria redesenhar é o ramo do menu, que só reage a
`redesenhar`. Resultado: a tela de "ALARME!" fica congelada na tela
por até mais `CONFIG_TIMEOUT_SEGUNDOS` segundos depois do alarme já
ter se calado sozinho, até o menu expirar por timeout. Correção
simples: também setar `redesenhar = true` nesse bloco de
autossilenciamento.

---

## 6. Usar o Alarme 2 do DS3231 como armazenamento de configuração

**Pedido:** guardar se o alarme está ativado e o nível de brilho no
DS3231, para sobreviver ao power-on (hoje o brilho sempre volta ao
máximo e a habilitação do alarme é a única coisa já persistida).

**Confirmado no código:** o projeto só usa o **Alarme 1** do DS3231
(registradores `07h`..`0Ah`, controle `0Eh` — ver
[ds3231.c](VFDCLK.X/ds3231.c)). Os registradores do **Alarme 2**
(`0Bh` minutos, `0Ch` horas, `0Dh` dia/data) não aparecem em nenhum
lugar do driver — estão livres e são alimentados pela mesma bateria,
exatamente como os do Alarme 1. Como o Alarme 2 nunca é armado/
habilitado (bit A2IE do controle permanece 0), esses 3 bytes nunca
disparam nada sozinhos: dá para tratá-los como uma pequena "EEPROM"
de 3 bytes, gratuita.

**Plano sugerido:**
- `alarme_ligado` já é persistido indiretamente pelo bit `A1IE` (não
  precisa duplicar);
- usar 1 desses 3 bytes (ex.: `0x0Bh`) para o **nível de brilho**
  (0..7, cabe fácil num byte; os outros 2 bytes ficam de reserva para
  futuras opções do menu, como o `CFG_NUM_OPCOES` já prevê
  crescimento);
- gravar apenas quando o valor mudar (troca de opção no menu), não a
  cada volta do laço — é EPROM/registrador de RTC, não precisa
  desgastar com escritas repetidas;
- ler no boot, junto com `ds3231_alarme_ler()`, antes de aplicar
  `vfd_brilho()` pela primeira vez.

Precisa de uma função nova tipo `ds3231_config_gravar()`/
`ds3231_config_ler()` em `ds3231.c/.h`, seguindo o mesmo padrão de
leitura/escrita crua de registrador já usado para o Alarme 1.

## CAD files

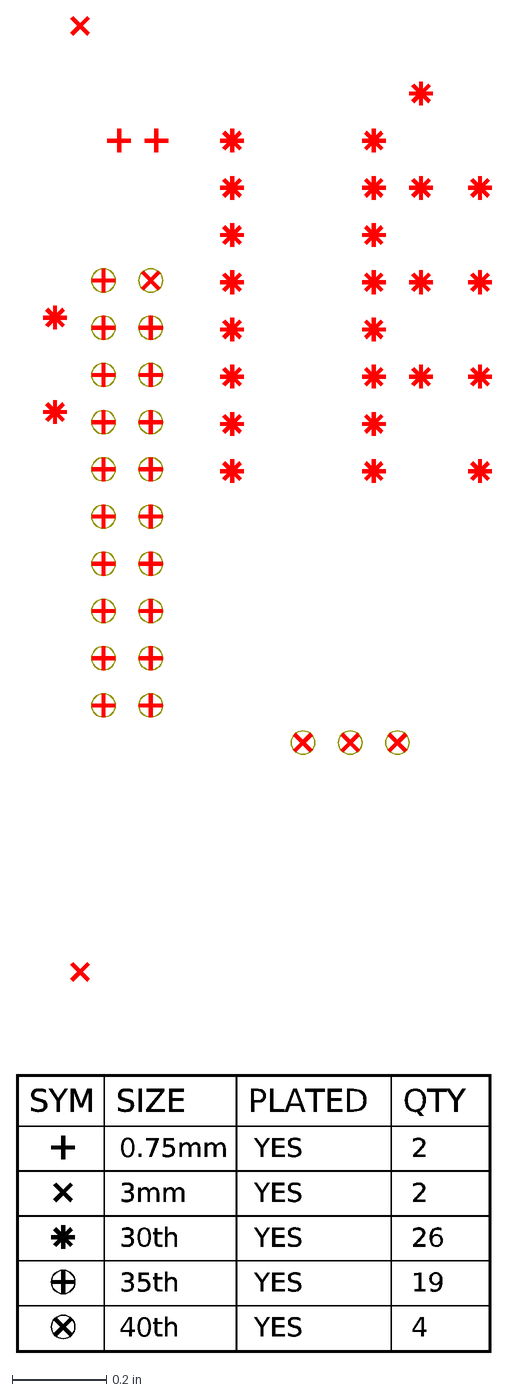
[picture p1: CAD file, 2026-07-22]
HARDWARE/AUXVFDBOARD/VFD_AUX.dxf
SYM
SIZE
PLATED
QTY
0.75mm
YES
2
3mm
30th
26
35th
19
40th
4

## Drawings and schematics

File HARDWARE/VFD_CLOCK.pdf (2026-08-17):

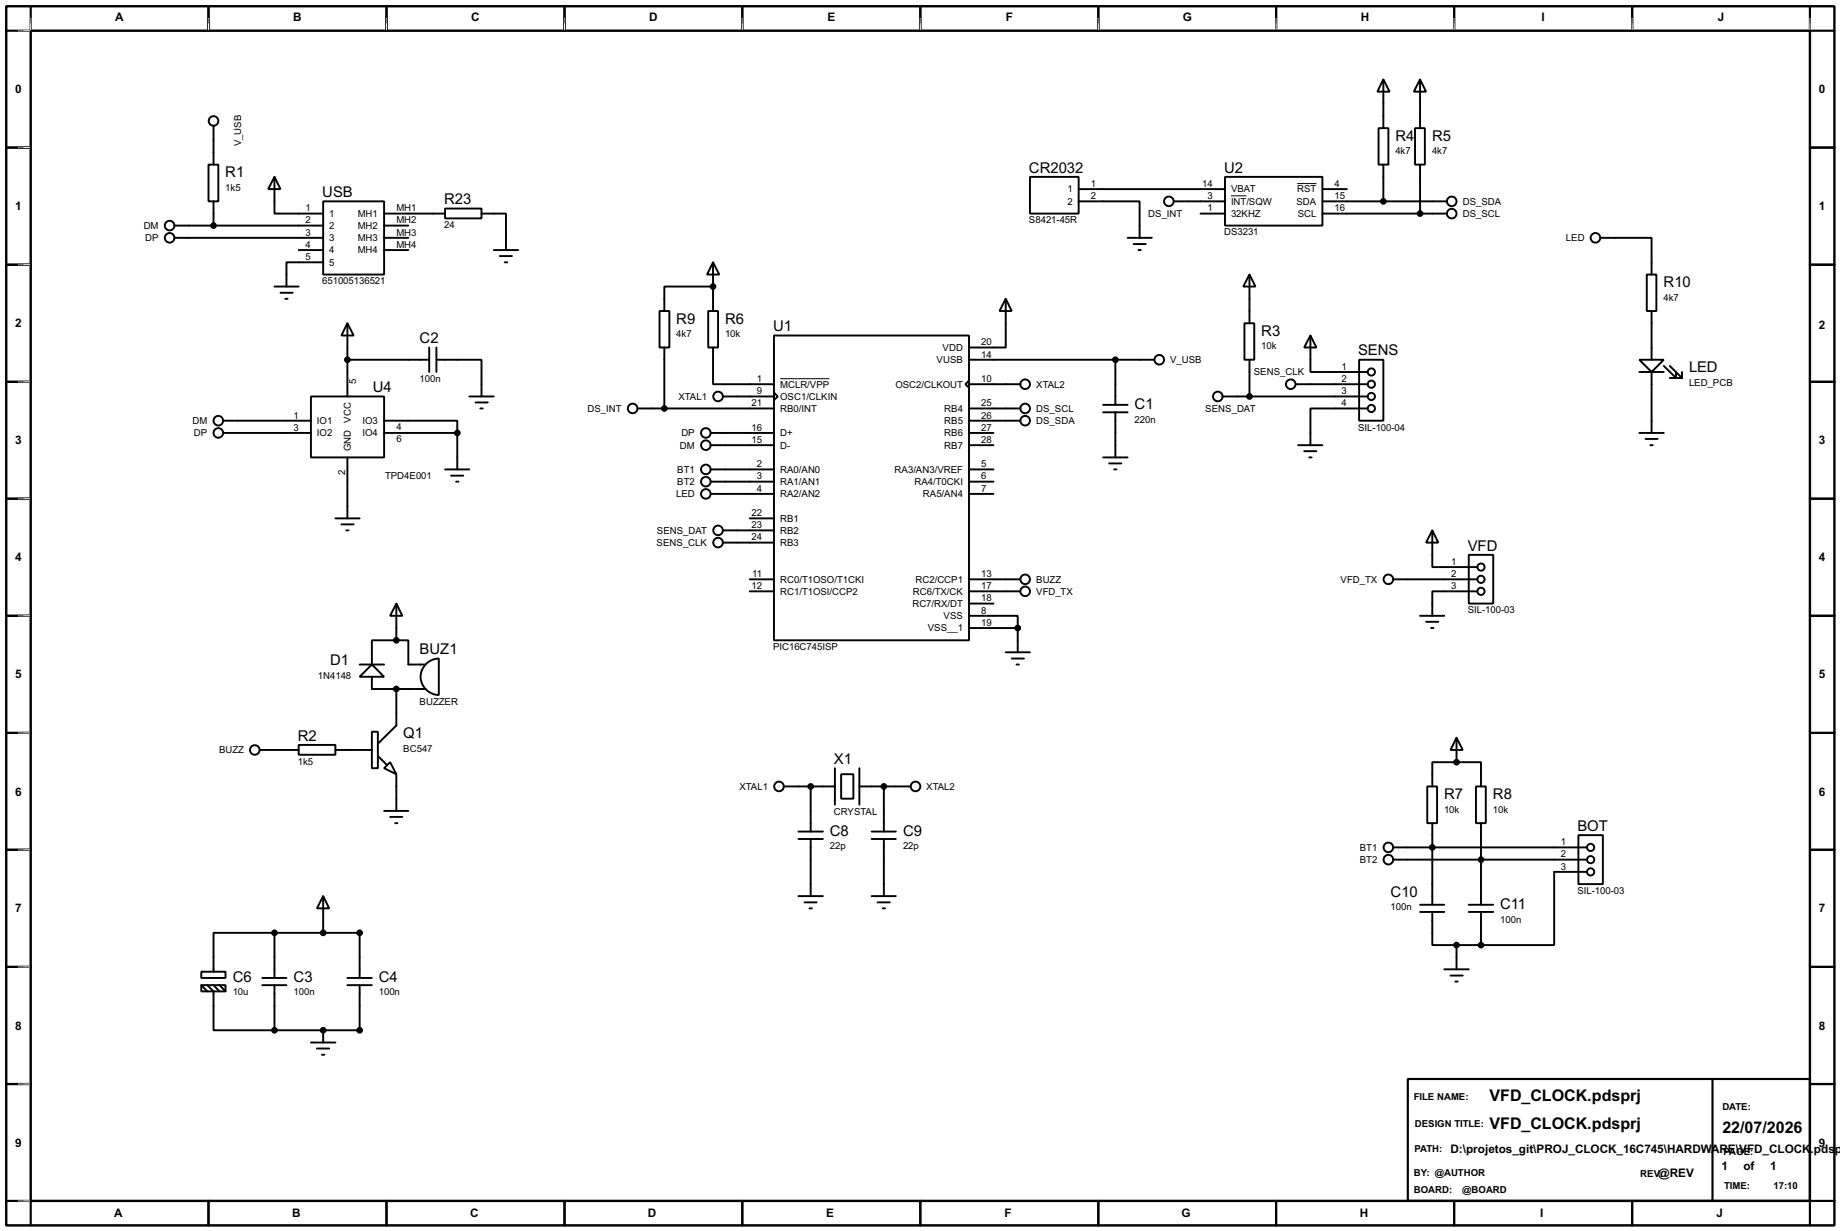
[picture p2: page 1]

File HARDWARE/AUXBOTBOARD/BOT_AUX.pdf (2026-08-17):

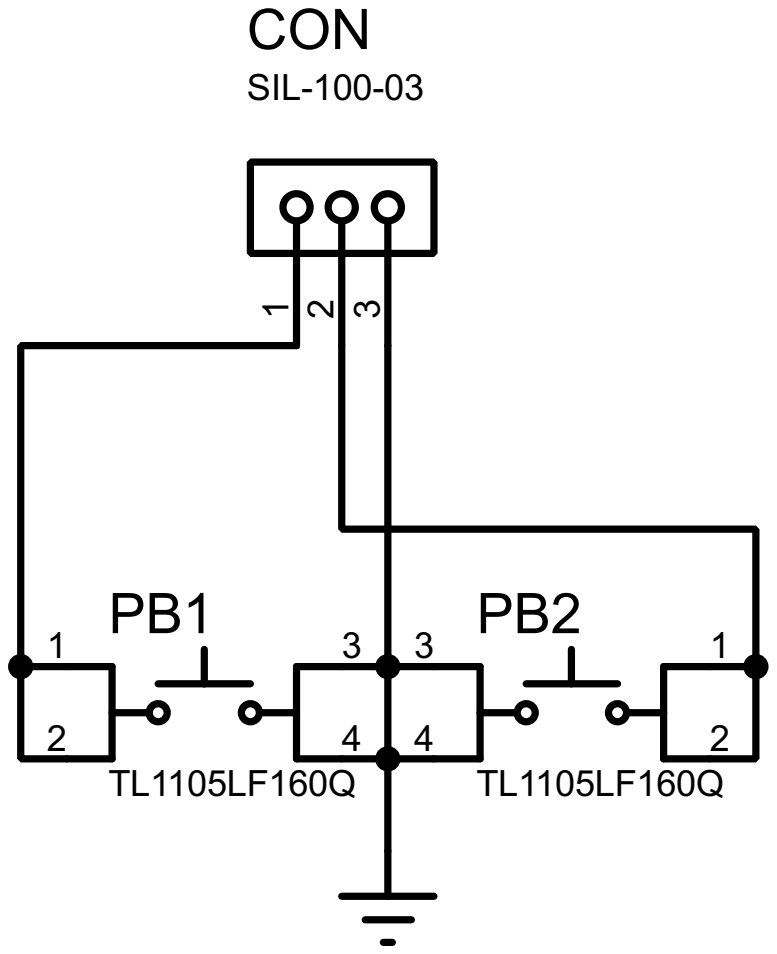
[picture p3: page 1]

PATH: D:\projetos_git\PROJ_CLOCK_16C745\HARDWARE\AUXBOTBOARD\BOT_AUX.pdsprj

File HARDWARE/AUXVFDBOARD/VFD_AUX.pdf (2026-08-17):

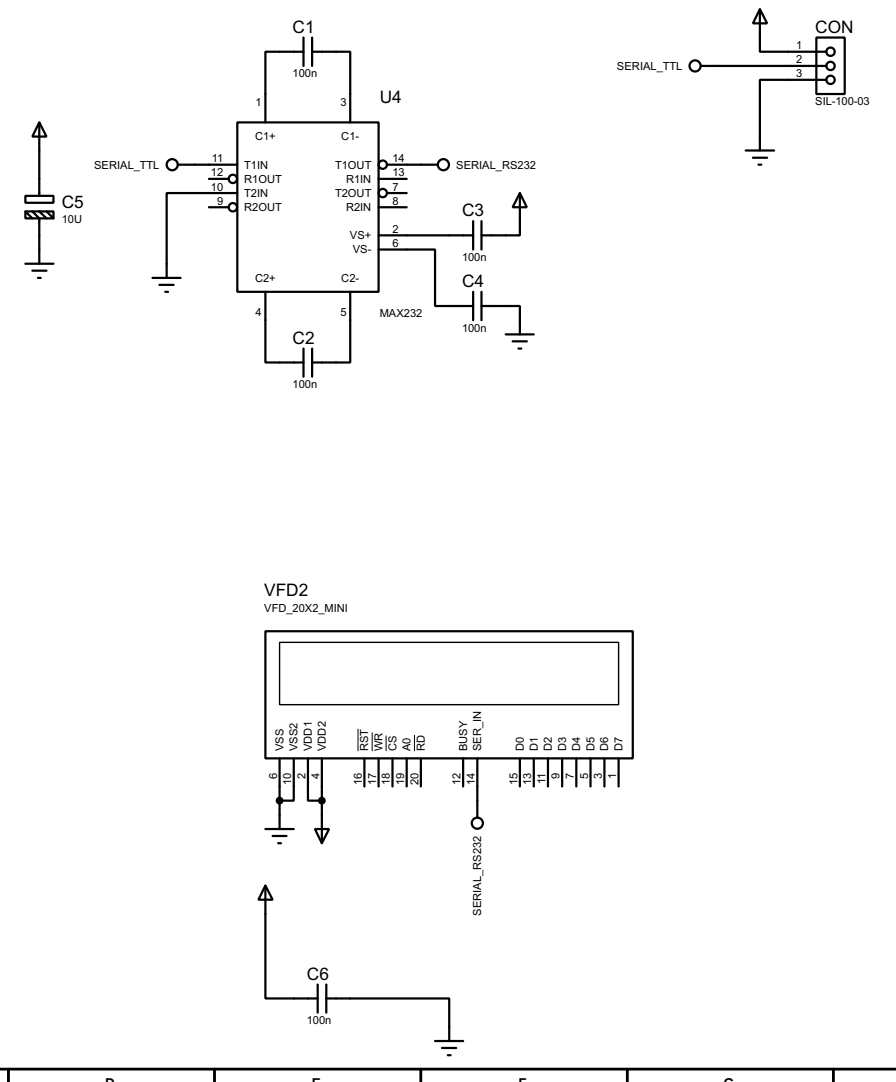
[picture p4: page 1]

PATH: D:\projetos_git\PROJ_CLOCK_16C745\HARDWARE\AUXVFDBOARD\VFD_AUX.pdsprj

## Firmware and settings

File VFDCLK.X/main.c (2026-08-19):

/**
 * =====================================================================
 *  main.c — Relógio VFD com PIC16C745 + DS3231 + SHT15
 * =====================================================================
 *  Funções:
 *   - exibe HORA/DATA no display VFD 20x2 (IEE 036X2, modo serial),
 *     alternando com TEMPERATURA/UMIDADE (Sensirion SHT15);
 *   - mantém a hora num RTC DS3231 (I2C por software, com bateria);
 *   - ao conectar no USB do PC, o utilitário DTCAPP/dtc_sync.py envia
 *     a hora local e o firmware atualiza o RTC (dispositivo HID, sem
 *     driver). O stack USB roda inteiro por interrupção (usb_hid.c).
 *
 *  A TELA (20x2): a LINHA DE CIMA é SEMPRE o relógio, com o sino na
 *  última coluna quando o alarme está habilitado. Só a LINHA DE BAIXO
 *  alterna, num carrossel de 6 s / 4 s:
 *        14:35:27         (sempre)          14:35:27           F
 *     QUA 16/07/2026                     23.4 °C     45.2 %RH
 *
 *  ARQUITETURA DO LAÇO PRINCIPAL (cooperativo, sem RTOS):
 *   a cada ~50 ms lê o DS3231; quando o segundo vira:
 *     - redesenha a tela (ou só os segundos, se nada mais mudou);
 *     - alterna a linha de baixo do carrossel (6 s data / 4 s clima);
 *     - a cada 30 s dispara uma medição do SHT15 (bloqueante ~0,4 s;
 *       a ISR de USB continua atendendo o barramento normalmente);
 *     - atualiza o report de estado que o PC pode ler via USB.
 *   fora do tick, verifica os botões e se chegou acerto pelo USB.
 *
 *  ALARME: dispara SOMENTE em dia útil (segunda a sexta), fixo — não há
 *  opção de menu para isso. No fim de semana o disparo é apenas
 *  reconhecido, o que rearma o alarme para o dia seguinte.
 *
 *  INTERFACE DE BOTÕES (menu de configuração):
 *   - BOTÃO 1 (RA0) = NAVEGAR: abre o menu e percorre as opções
 *                     (por ora: ALARME e BRILHO). Nunca altera valor.
 *   - BOTÃO 2 (RA1) = ALTERAR: muda o valor da opção mostrada
 *                     (alarme liga/desliga; brilho sobe até o máximo e
 *                     volta ao mínimo). Fora do menu, o 1º toque já abre
 *                     no alarme e alterna, atendendo o gesto mais comum.
 *   Sem tocar em botão por 3 s, o menu fecha sozinho e o carrossel
 *   volta. Com o alarme TOCANDO, qualquer botão silencia.
 *
 *  Bits de configuração (datasheet DS41124D, seção 12.1):
 *   FOSC=HS -> cristal HS de 24 MHz direto, sem PLL (o USB low-speed
 *              exige exatamente 24 MHz); WDT LIGADO (auto-recuperação); PWRT ligado.
 * =====================================================================
 */
#include <xc.h>
#include <stdint.h>
#include <stdbool.h>

#include "board.h"
#include "uart.h"
#include "vfd.h"
#include "swi2c.h"
#include "ds3231.h"
#include "sht1x.h"
#include "usb_hid.h"
#include "botoes.h"

/* ------------------------------------------------------------------
 * Bits de configuração (gravados junto com o programa)
 * ------------------------------------------------------------------ */
#pragma config FOSC  = HS    /* cristal de 24 MHz (HS, sem PLL)       */
#pragma config WDTE  = ON    /* watchdog LIGADO: ver nota em ESPERAR_MS */
#pragma config PWRTE = ON    /* power-up timer: alimentação estável   */
#pragma config CP    = OFF   /* sem proteção de código                */

/* ------------------------------------------------------------------
 * Ajustes de comportamento (fáceis de personalizar)
 * ------------------------------------------------------------------ */
#define TELA_HORA_SEGUNDOS    6u   /* tempo exibindo hora/data        */
#define TELA_CLIMA_SEGUNDOS   4u   /* tempo exibindo temp/umidade     */
#define SHT_PERIODO_SEGUNDOS  30u  /* intervalo entre medições        */
#define MSG_SYNC_SEGUNDOS     3u   /* aviso "hora sincronizada"       */
#define ALARME_MAX_SEGUNDOS   60u  /* silencia sozinho após ~1 min    */
#define REFRESCO_SEGUNDOS     900u /* redesenho completo de auto-correção
                                    * (15 min): repõe cursor e reescreve
                                    * a tela toda, curando qualquer
                                    * desalinhamento por ruído          */
#define CONFIG_TIMEOUT_SEGUNDOS 3u /* menu fecha sozinho após ocioso   */
#define BRILHO_PADRAO         VFD_BRILHO_MAXIMO

/* ------------------------------------------------------------------
 * OS DOIS SÍMBOLOS DA TELA — vêm por caminhos DIFERENTES
 * ------------------------------------------------------------------
 * GRAU: é caractere NATIVO da fonte deste módulo, em B9h. Foi
 * localizado na bancada varrendo a tabela do display. Entra no fluxo
 * como qualquer letra, sem comando nenhum — ver VFD_CHAR_GRAU_NATIVO.
 *
 * SINO: não existe na fonte, então é DESENHADO com o comando 18h e
 * guardado no slot F6h. A gravação acontece dentro de vfd_iniciar(),
 * com o mesmo código que funciona no projeto do PIC18F2550 — ver a
 * nota longa em vfd.c. O interruptor USAR_SIMBOLOS_PROPRIOS (vfd.h)
 * troca o sino por '*' se for preciso isolar esse comando.           */

/* Bipe do alarme e pisca sincronizado. Base de tempo REAL vinda do TMR1
 * (não das voltas do laço), então o ritmo não "engasga" quando uma volta
 * demora mais. Período de 500 ms; buzzer e texto LIGADOS nos primeiros
 * 200 ms de cada período (200 ms ON / 300 ms OFF).
 *
 * O TMR1 usa o pino RC0 (T1OSO/T1CKI); por isso o LED de heartbeat foi
 * movido para RA2 (ver board.h) — ligar o TMR1 tirava o LED do RC0.     */
#define ALARME_PERIODO_MS   500u
#define ALARME_BIPE_ON_MS   200u

/* TMR1 livre: clock = Fosc/4 = 6 MHz, prescaler 1:8 -> 750 kHz -> 750
 * ticks por milissegundo. Overflow do contador de 16 bits em ~87 ms,
 * bem acima da volta do laço (~50 ms), então o delta por volta é sempre
 * capturado corretamente com uma subtração de 16 bits.                 */
#define TMR1_TICKS_POR_MS   750u

/* Telas do CARROSSEL automático. Só hora e clima se alternam sozinhas;
 * o alarme SAIU do rodízio — agora é uma opção do menu de configuração
 * (ver tela_config e o tratamento dos botões no laço principal).      */
#define TELA_HORA        0u
#define TELA_CLIMA       1u
#define CARROSSEL_TELAS  2u

/* Opções do menu de configuração (botão 1 escolhe, botão 2 altera).
 * Estender é simples: acrescente uma opção aqui, trate-a no botão 2 e
 * em tela_config(), e aumente CFG_NUM_OPCOES.                         */
#define CFG_ALARME       0u
#define CFG_BRILHO       1u
#define CFG_NUM_OPCOES   2u

/* Sombra do latch de PORTB — ver explicação em board.h               */
volatile uint8_t portb_sombra;

/* ------------------------------------------------------------------
 * Inicialização dos pinos (declarada em board.h)
 * ------------------------------------------------------------------ */
void board_iniciar_pinos(void)
{
    /* PORTA: RA0 = botão 1 (navegar), RA1 = botão 2 (alterar), ambos
     * entradas para GND com pull-up externo de 10k. RA2 = LED de
     * heartbeat (SAÍDA). ADCON1 com PCFG=0b111 põe TODOS os canais em
     * modo digital — indispensável para ler RA0/RA1 como entradas e
     * acionar RA2 como saída digital (ver seção 11 do DS41124D).      */
    ADCON1 = 0x07;
    LED_HB_DESLIGAR();                   /* RA2=0 no latch antes de saída */
    TRISA  = (uint8_t)~LED_HB_MASCARA;   /* RA2 saída; RA0/RA1 entradas   */

    /* PORTB:
     *  RB5 (SDA) e RB2 (DATA SHT): latch 0, iniciam SOLTOS (TRIS=1)
     *  RB4 (SCL) e RB3 (SCK)     : saídas push-pull, iniciam em nível
     *                              de repouso (SCL=1 alto, SCK=0 baixo)
     *  RB0 (INT/SQW do DS3231)   : ENTRADA (INT0; uso futuro, ver board.h)
     *  RB1, RB6, RB7             : entradas (RB1 livre; RB6/7 = ICSP)  */
    portb_sombra = I2C_SCL_MASCARA;      /* SCL=1, SCK=0, SDA=DATA=0 */
    PORTB_APLICAR();
    TRISB = (uint8_t)~(I2C_SCL_MASCARA | SHT_SCK_MASCARA);
    /* = 0b11100111: SCL(RB4) e SCK(RB3) saídas; demais entradas —
     *   SDA/DATA soltos (open-drain), RB0=INT/SQW, RB1 livre, RB6/7 ICSP */

    /* PORTC: RC6 = TX (o USART assume o controle do pino quando
     * TXEN=1/SPEN=1); RC4/RC5 são do USB; RC2 = buzzer é a única saída.
     * RC0 (T1OSO/T1CKI) fica como ENTRADA, livre para o TMR1. Demais
     * como entrada. (O LED de heartbeat mudou para RA2 — ver board.h.) */
    BUZZER_DESLIGAR();                  /* estado definido ANTES de   */
                                        /* virar saída                */
    TRISC = (uint8_t)~BUZZER_MASCARA;   /* só RC2 (buzzer) saída; RC0
                                         * fica entrada, livre p/ o TMR1 */
}

/* ------------------------------------------------------------------
 * Estado global do relógio
 * ------------------------------------------------------------------ */
static ds3231_hora_t  hora_atual;
static sht1x_medida_t medida;              /* última leitura do SHT15 */
static bool ha_medida    = false;          /* já houve leitura boa?   */
static bool rtc_presente = false;          /* DS3231 respondeu?       */
static bool hora_valida  = false;          /* OSF limpo no DS3231?    */

/* Estado do alarme. O horário e a habilitação VIVEM NO DS3231 (na
 * bateria); estas variáveis são só um espelho para exibir sem ter de
 * reler o RTC a cada redesenho.                                      */
static uint8_t alarme_horas    = 0x07u;    /* BCD (padrão 07:00)      */
static uint8_t alarme_minutos  = 0x00u;    /* BCD                     */
static bool    alarme_ligado   = false;    /* espelho do bit A1IE     */
static bool    alarme_tocando  = false;    /* disparou e não foi calado */
static uint8_t alarme_segundos = 0;        /* há quanto tempo toca    */

/* Brilho corrente do display (hardware: 0 = máximo ... 7 = mínimo).
 * O PIC16C745 não tem EEPROM e o DS3231 não tem SRAM livre, então o
 * brilho NÃO é retido no desligamento: volta ao padrão a cada boot.   */
static uint8_t brilho_nivel = BRILHO_PADRAO;

/* Espelho do que está ESCRITO na tela de hora, para atualizar só os
 * dígitos que mudarem (ver tela_principal). 0xFF = desconhecido, força a
 * primeira escrita.                                                  */
static uint8_t exibido_horas    = 0xFFu;
static uint8_t exibido_minutos  = 0xFFu;
static uint8_t exibido_segundos = 0xFFu;

/* Nomes dos dias da semana (1 = segunda ... 7 = domingo)             */
static const char * const nome_dia[7] = {
    "SEG", "TER", "QUA", "QUI", "SEX", "SAB", "DOM"
};

/* ------------------------------------------------------------------
 * Interrupção única do PIC16 midrange: despacha para o stack USB.
 * A flag PIR1.USBIF é limpa ANTES de servir as flags detalhadas do
 * UIR: se um novo evento chegar durante o atendimento, USBIF volta a
 * subir e a ISR reentra — nenhum evento é perdido.
 * ------------------------------------------------------------------ */
void __interrupt() interrupcao(void)
{
    if (PIE1bits.USBIE && PIR1bits.USBIF) {
        PIR1bits.USBIF = 0;
        usb_isr();
    }
}

/* ------------------------------------------------------------------
 * Formatação de texto (sem printf: economiza ~1,5 K words de ROM)
 * ------------------------------------------------------------------ */

/* Escreve os 2 dígitos de um valor BCD em p[0..1]                    */
static void por_bcd(char *p, uint8_t bcd)
{
    p[0] = (char)('0' + (bcd >> 4));
    p[1] = (char)('0' + (bcd & 0x0Fu));
}

/* Copia uma string para o buffer a partir da coluna 'col', sem passar
 * do fim da linha. Usada para montar as telas de forma legível.      */
static void por_texto(char *b, uint8_t col, const char *s)
{
    while ((*s != '\0') && (col < VFD_COLUNAS)) {
        b[col] = *s;
        col++;
        s++;
    }
}

/* Escreve um valor em décimos como "xx.d", alinhado à DIREITA,
 * terminando na posição 'fim' (ex.: -53 -> "-5.3").                  */
/* As divisões por 10 são feitas por SUBTRAÇÃO REPETIDA, de propósito.
 * Em 16 bits, "/" e "%" viram chamadas a ___lwdiv/___lwmod, e cada
 * chamada custa um nível da pilha de hardware de 8 posições que o main
 * divide com a ISR do USB (ver a nota de PROFUNDIDADE DE PILHA em
 * main()). Os valores aqui são pequenos (décimos de grau e de %RH, no
 * máximo 3 dígitos), então o custo em tempo é irrelevante: algumas
 * dezenas de subtrações, uma vez a cada 30 s.                        */
static void por_decimos(char *fim, int16_t valor)
{
    bool negativo = (valor < 0);
    uint16_t v = negativo ? (uint16_t)(-valor) : (uint16_t)valor;
    uint8_t  inteiro = 0;            /* v/10 <= 100: cabe em 8 bits   */
    uint8_t  q;

    while (v >= 10u) {               /* inteiro = v/10, v = v%10      */
        v -= 10u;
        inteiro++;
    }
    *fim-- = (char)('0' + (uint8_t)v);
    *fim-- = '.';

    do {
        q = 0;
        while (inteiro >= 10u) {     /* q = inteiro/10, resto em inteiro */
            inteiro -= 10u;
            q++;
        }
        *fim-- = (char)('0' + (uint8_t)inteiro);
        inteiro = q;
    } while (inteiro != 0u);

    if (negativo) {
        *fim = '-';
    }
}

/* Preenche um buffer de linha com espaços (20 colunas + terminador)  */
static void linha_limpa(char *b)
{
    uint8_t i;

    for (i = 0; i < VFD_COLUNAS; i++) {
        b[i] = ' ';
    }
    b[VFD_COLUNAS] = '\0';
}
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
void main(void)
{
    uint8_t seg_anterior   = 0xFFu;  /* força 1º redesenho            */
    uint8_t cont_tela      = 0;      /* segundos na tela corrente     */
    uint8_t tela           = TELA_HORA;            /* tela ativa      */
    uint8_t cont_sht       = SHT_PERIODO_SEGUNDOS; /* mede já no boot */
    uint8_t cont_msg_sync  = 0;      /* aviso de sincronização        */
    uint16_t tmr1_ant      = 0;      /* última leitura do TMR1 (base tempo) */
    uint16_t acum_ticks    = 0;      /* ticks do TMR1 acumulados (<750/ms)  */
    uint16_t fase_ms       = 0;      /* fase 0..499 ms do bipe/pisca alarme */
    bool    redesenhar     = false;  /* forçado por botão/comando     */
    uint8_t tela_desenhada = 0xFFu;  /* qual tela está pintada        */
    uint8_t hb_contador    = 0;      /* divisor do heartbeat (LED)    */
    bool    hb_estado      = false;  /* estado atual do LED           */
    uint16_t cont_refresco = 0;      /* segundos até o refresco total */
    bool    alarme_desenhado = false;/* tela de alarme já pintada     */
    bool    alarme_visivel   = false;/* estado atual do pisca (texto on?) */
    bool    modo_config    = false;  /* menu de configuração aberto?  */
    uint8_t opcao_config   = CFG_ALARME;  /* opção mostrada no menu   */
    uint8_t cont_config    = 0;      /* segundos ocioso no menu        */
    bool    btn1;                    /* botão 1 (navegar) tocado?     */
    bool    btn2;                    /* botão 2 (alterar) tocado?     */
    uint8_t acerto[USB_TAM_REPORT];
    uint8_t estado[USB_TAM_REPORT];  /* report montado a cada tick    */

    /* Duração de cada tela no carrossel automático (índice = tela)   */
    static const uint8_t tela_duracao[CARROSSEL_TELAS] = {
        TELA_HORA_SEGUNDOS, TELA_CLIMA_SEGUNDOS
    };

    /* ---- inicialização de hardware -------------------------------- */
    board_iniciar_pinos();
    uart_iniciar();
    i2c_iniciar_barramento();
    sht1x_reset_comunicacao();

    /* TMR1 como contador LIVRE (sem interrupção), base de tempo real do
     * bipe/pisca do alarme. T1CON: TMR1CS=0 (clock Fosc/4), T1OSCEN=0
     * (oscilador desligado), T1CKPS=11 (prescaler 1:8), TMR1ON=1 -> 0x31.
     * Usa o pino RC0 (por isso o LED foi para RA2 — ver board.h).       */
    T1CON = 0x31u;

    /* USB primeiro (com GIE ainda apagado), depois interrupções: o
     * host começa a enumerar em paralelo com o resto do boot.        */
    usb_iniciar();
    INTCONbits.PEIE = 1;
    INTCONbits.GIE  = 1;

    /* O display exige 500 ms de power-up (a espera está dentro de
     * vfd_iniciar); a enumeração USB acontece durante essa espera.   */
    vfd_iniciar();
#if USAR_SIMBOLOS_PROPRIOS
    /* Sino: logo após o reset por software do display (dentro de
     * vfd_iniciar) e chamado DAQUI, não de lá — ver a nota de pilha
     * em vfd.c.                                                       */
    vfd_definir_sino();
#endif
    /* Restaura o brilho salvo (área de config do DS3231); se nunca foi
     * gravado, brilho_nivel mantém o padrão (BRILHO_PADRAO).          */
    {
        uint8_t b;
        if (ds3231_config_ler(&b)) {
            brilho_nivel = b;
        }
    }
    vfd_brilho(brilho_nivel);
    vfd_quadro("  VFDCLK VER. 1.0", "    Bruno Tondin");

    hora_valida = ds3231_hora_valida();
    /* Recupera o alarme guardado na bateria do RTC (o PIC não tem
     * EEPROM, então o DS3231 é a única memória não-volátil do
     * projeto — ver comentário em ds3231.h).                         */
    (void)ds3231_alarme_ler(&alarme_horas, &alarme_minutos, &alarme_ligado);
    /* Descarta um disparo antigo: o RTC continua casando o horário na
     * bateria com o aparelho desligado, então A1F pode estar setado de
     * um alarme que já passou. Sem isto, ligar o relógio depois da
     * hora do alarme faria ele tocar imediatamente.                  */
    (void)ds3231_alarme_reconhecer();
    ESPERAR_MS(1000);                /* splash rapidinho              */

    /* ---- laço principal ------------------------------------------- */
    for (;;) {
        /* Alimenta o watchdog uma vez por volta. Se o laço travar por
         * qualquer motivo (I2C preso, retorno corrompido, espera sem
         * fim), o WDT reinicia o PIC em ~2,3 s e o relógio se recupera
         * sozinho em vez de ficar morto na bancada. A volta mais lenta
         * é a que mede o SHT15 (~0,4 s), bem abaixo do pior caso do
         * temporizador (~0,9 s) — ver ESPERAR_MS em board.h.         */
        CLRWDT();

        /* 0) Botões: o debounce conta voltas do laço (~50 ms cada),
         *    por isso botoes_processar() vem SEMPRE, uma vez por volta.
         *    Qualquer toque (curto ou longo) conta como um "clique".  */
        botoes_processar();
        btn1 = (botao_evento(BTN_TELA)   != BTN_NADA);
        btn2 = (botao_evento(BTN_ALARME) != BTN_NADA);

        /* 0a) Alarme TOCANDO: qualquer botão silencia (e rearma para
         *     amanhã). É o gesto natural — ouviu, apertou, parou.     */
        if (alarme_tocando && (btn1 || btn2)) {
            alarme_tocando = false;
            (void)ds3231_alarme_reconhecer();
            BUZZER_DESLIGAR();
            redesenhar = true;
            btn1 = false;                 /* consumidos pelo silenciar  */
            btn2 = false;
        }

        /* 0b) Botão 1 — NAVEGAR: abre o menu ou avança a opção. Nunca
         *     altera valor.                                            */
        if (btn1) {
            if (!modo_config) {
                modo_config  = true;
                opcao_config = CFG_ALARME;
            } else {
                opcao_config = (uint8_t)((opcao_config + 1u) % CFG_NUM_OPCOES);
            }
            cont_config = 0;
            redesenhar  = true;
        }

        /* 0c) Botão 2 — ALTERAR o valor da opção atual. Se o menu ainda
         *     não estava aberto, abre na 1ª opção (alarme) e já alterna,
         *     dando resposta imediata ao gesto mais comum.            */
        if (btn2) {
            if (!modo_config) {
                modo_config  = true;
                opcao_config = CFG_ALARME;
            }
            if (opcao_config == CFG_ALARME) {
                alarme_ligado = !alarme_ligado;
                (void)ds3231_alarme_habilitar(alarme_ligado);
            } else {   /* CFG_BRILHO: sobe o brilho; do máximo, volta ao
                        * mínimo. Hardware 0 = máx.; subir brilho = N--. */
                if (brilho_nivel == VFD_BRILHO_MAXIMO) {
                    brilho_nivel = VFD_BRILHO_MINIMO;
                } else {
                    brilho_nivel--;
                }
                vfd_brilho(brilho_nivel);
                /* Persiste na área de config do DS3231 (só quando muda,
                 * não a cada volta) para sobreviver ao desligamento.   */
                (void)ds3231_config_gravar(brilho_nivel);
            }
            cont_config = 0;
            redesenhar  = true;
        }

        /* 0d) Base de tempo REAL a partir do TMR1 livre. A fase anda
         *     conforme o tempo de VERDADE decorrido (delta de ticks do
         *     TMR1), não conforme as voltas do laço — então o bipe não
         *     "engasga" quando uma volta demora mais. Leitura em laço
         *     (reamostra enquanto o byte alto mudar) para não pegar o
         *     contador no meio de um rollover.                          */
        {
            uint8_t  hi, lo;
            uint16_t agora;
            uint16_t delta;

            do {
                hi = TMR1H;
                lo = TMR1L;
            } while (hi != TMR1H);
            agora = (uint16_t)(((uint16_t)hi << 8) | lo);
            delta = (uint16_t)(agora - tmr1_ant);   /* tolera 1 overflow */
            tmr1_ant = agora;

            acum_ticks = (uint16_t)(acum_ticks + delta);
            while (acum_ticks >= TMR1_TICKS_POR_MS) {
                acum_ticks = (uint16_t)(acum_ticks - TMR1_TICKS_POR_MS);
                if (++fase_ms >= ALARME_PERIODO_MS) {
                    fase_ms = 0;
                }
            }
        }

        /* 0e) Bipe + pisca do alarme, ambos derivados da MESMA fase:
         *     LIGADOS nos primeiros ALARME_BIPE_ON_MS de cada período
         *     (200 ms ON / 300 ms OFF). Como texto e som saem da mesma
         *     base de tempo, piscam juntos. A tela do alarme é desenhada
         *     AQUI (não no tick de 1 s), pois pisca mais rápido que isso.
         *     Fora do alarme: NÃO mexe no pino do buzzer toda volta (já
         *     foi desligado ao silenciar) — evita read-modify-write no
         *     PORTC à toa.                                              */
        if (alarme_tocando) {
            bool visivel = (fase_ms < ALARME_BIPE_ON_MS);
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

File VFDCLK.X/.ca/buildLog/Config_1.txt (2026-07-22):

make -f nbproject/Makefile-Config_1.mk SUBPROJECTS= .clean-conf
make[1]: Entering directory 'D:/projetos_git/PROJ_CLOCK_16C745/VFDCLK.X'
rm -f  -r .ca/build/Config_1/production
rm -f  -r .ca/dist/Config_1/production
make[1]: Leaving directory 'D:/projetos_git/PROJ_CLOCK_16C745/VFDCLK.X'
[32mCLEAN SUCCESSFUL (total time: 100ms)[0m
make -f nbproject/Makefile-Config_1.mk SUBPROJECTS= .build-conf
make  -f nbproject/Makefile-Config_1.mk .ca/dist/Config_1/production/VFDCLK.X.production.hex
make[2]: Entering directory 'D:/projetos_git/PROJ_CLOCK_16C745/VFDCLK.X'
"D:\Program Files\Microchip\xc8\v4.00\bin\xc8-cc.exe"  -mcpu=16C745 -c   -mdfp="D:/Program Files/Microchip/MPLABX/v6.30/packs/Microchip/PIC12-16Cxxx_DFP/1.7.175/xc8"  -O1 -fasmfile -maddrqual=ignore -xassembler-with-cpp -mwarn=-3 -Wa,-a -DXPRJ_Config_1=Config_1  -msummary=-psect,-class,+mem,-hex,-file  -ginhx32 -Wl,--data-init -mno-keep-startup -mno-osccal -mno-resetbits -mno-save-resetbits -mno-download -mno-stackcall -mno-default-config-bits   -std=c99 -gdwarf-3 -mstack=compiled:auto:auto     -o .ca/build/Config_1/production/uart.p1 uart.c 
make[2]: Leaving directory 'D:/projetos_git/PROJ_CLOCK_16C745/VFDCLK.X'
make[2]: Entering directory 'D:/projetos_git/PROJ_CLOCK_16C745/VFDCLK.X'
"D:\Program Files\Microchip\xc8\v4.00\bin\xc8-cc.exe"  -mcpu=16C745 -c   -mdfp="D:/Program Files/Microchip/MPLABX/v6.30/packs/Microchip/PIC12-16Cxxx_DFP/1.7.175/xc8"  -O1 -fasmfile -maddrqual=ignore -xassembler-with-cpp -mwarn=-3 -Wa,-a -DXPRJ_Config_1=Config_1  -msummary=-psect,-class,+mem,-hex,-file  -ginhx32 -Wl,--data-init -mno-keep-startup -mno-osccal -mno-resetbits -mno-save-resetbits -mno-download -mno-stackcall -mno-default-config-bits   -std=c99 -gdwarf-3 -mstack=compiled:auto:auto     -o .ca/build/Config_1/production/usb_desc.p1 usb_desc.c 
make[2]: Leaving directory 'D:/projetos_git/PROJ_CLOCK_16C745/VFDCLK.X'
make[2]: Entering directory 'D:/projetos_git/PROJ_CLOCK_16C745/VFDCLK.X'
"D:\Program Files\Microchip\xc8\v4.00\bin\xc8-cc.exe"  -mcpu=16C745 -c   -mdfp="D:/Program Files/Microchip/MPLABX/v6.30/packs/Microchip/PIC12-16Cxxx_DFP/1.7.175/xc8"  -O1 -fasmfile -maddrqual=ignore -xassembler-with-cpp -mwarn=-3 -Wa,-a -DXPRJ_Config_1=Config_1  -msummary=-psect,-class,+mem,-hex,-file  -ginhx32 -Wl,--data-init -mno-keep-startup -mno-osccal -mno-resetbits -mno-save-resetbits -mno-download -mno-stackcall -mno-default-config-bits   -std=c99 -gdwarf-3 -mstack=compiled:auto:auto     -o .ca/build/Config_1/production/swi2c.p1 swi2c.c 
make[2]: Leaving directory 'D:/projetos_git/PROJ_CLOCK_16C745/VFDCLK.X'
make[2]: Entering directory 'D:/projetos_git/PROJ_CLOCK_16C745/VFDCLK.X'
"D:\Program Files\Microchip\xc8\v4.00\bin\xc8-cc.exe"  -mcpu=16C745 -c   -mdfp="D:/Program Files/Microchip/MPLABX/v6.30/packs/Microchip/PIC12-16Cxxx_DFP/1.7.175/xc8"  -O1 -fasmfile -maddrqual=ignore -xassembler-with-cpp -mwarn=-3 -Wa,-a -DXPRJ_Config_1=Config_1  -msummary=-psect,-class,+mem,-hex,-file  -ginhx32 -Wl,--data-init -mno-keep-startup -mno-osccal -mno-resetbits -mno-save-resetbits -mno-download -mno-stackcall -mno-default-config-bits   -std=c99 -gdwarf-3 -mstack=compiled:auto:auto     -o .ca/build/Config_1/production/main.p1 main.c 
make[2]: Leaving directory 'D:/projetos_git/PROJ_CLOCK_16C745/VFDCLK.X'
make[2]: Entering directory 'D:/projetos_git/PROJ_CLOCK_16C745/VFDCLK.X'
"D:\Program Files\Microchip\xc8\v4.00\bin\xc8-cc.exe"  -mcpu=16C745 -c   -mdfp="D:/Program Files/Microchip/MPLABX/v6.30/packs/Microchip/PIC12-16Cxxx_DFP/1.7.175/xc8"  -O1 -fasmfile -maddrqual=ignore -xassembler-with-cpp -mwarn=-3 -Wa,-a -DXPRJ_Config_1=Config_1  -msummary=-psect,-class,+mem,-hex,-file  -ginhx32 -Wl,--data-init -mno-keep-startup -mno-osccal -mno-resetbits -mno-save-resetbits -mno-download -mno-stackcall -mno-default-config-bits   -std=c99 -gdwarf-3 -mstack=compiled:auto:auto     -o .ca/build/Config_1/production/ds3231.p1 ds3231.c 
make[2]: Leaving directory 'D:/projetos_git/PROJ_CLOCK_16C745/VFDCLK.X'
make[2]: Entering directory 'D:/projetos_git/PROJ_CLOCK_16C745/VFDCLK.X'
"D:\Program Files\Microchip\xc8\v4.00\bin\xc8-cc.exe"  -mcpu=16C745 -c   -mdfp="D:/Program Files/Microchip/MPLABX/v6.30/packs/Microchip/PIC12-16Cxxx_DFP/1.7.175/xc8"  -O1 -fasmfile -maddrqual=ignore -xassembler-with-cpp -mwarn=-3 -Wa,-a -DXPRJ_Config_1=Config_1  -msummary=-psect,-class,+mem,-hex,-file  -ginhx32 -Wl,--data-init -mno-keep-startup -mno-osccal -mno-resetbits -mno-save-resetbits -mno-download -mno-stackcall -mno-default-config-bits   -std=c99 -gdwarf-3 -mstack=compiled:auto:auto     -o .ca/build/Config_1/production/vfd.p1 vfd.c 
make[2]: Leaving directory 'D:/projetos_git/PROJ_CLOCK_16C745/VFDCLK.X'
make[2]: Entering directory 'D:/projetos_git/PROJ_CLOCK_16C745/VFDCLK.X'
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

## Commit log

2026-07-17 Projeto inicial: relógio VFD com PIC16C745 (firmware + app + docs)
    Firmware (VFDCLK.X, MPLAB XC8 v4.00) para PIC16C745:
    - display VFD IEE 036X2 (20x2) em modo serial 9600 8N1
    - RTC DS3231 via I2C por software (bit-bang, open-drain por TRIS)
    - sensor Sensirion SHT15 (Sensibus) com CRC-8 e conversao em ponto fixo
    - stack USB HID low-speed por interrupcao (capitulo 9 + classe HID),
    acerto de hora do PC via SET_REPORT gravado no DS3231
    - laco principal cooperativo alternando hora/data e temperatura/umidade
    Utilitario do PC (DTCAPP, Python/hidapi):
    - dtc_sync.py: envia a hora local ao relogio (manual, sem driver)
    - teste_conversao.py: valida a matematica do SHT15 vs formulas oficiais
    Documen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
    [ds3231.c, main.c, swi2c.c]
2026-07-17 Adiciona .gitattributes (normalizacao de fim de linha)
2026-07-17 Adiciona heartbeat de LED para teste de bring-up
    Este código temporário pisca um LED em RC0 a 1 Hz, travando a execução do firmware principal. É destinado à verificação inicial do hardware em protótipo, confirmando o funcionamento da alimentação, cristal de clock (e PLL), e reset do PIC. Deve ser removido para operação normal do relógio.
    [main.c]
2026-07-17 Atualiza cristal de clock e interface serial do VFD para maior robustez
    O cristal de 6 MHz com PLL é substituído por um de 24 MHz (modo HS), simplificando o clock e atendendo diretamente os requisitos do USB. O inversor serial de 1 transistor para o display VFD é trocado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
2026-07-17 Atualiza projeto Proteus
    Reflete as modificações de hardware para o cristal de clock e interface serial do VFD.
2026-07-20 Remove heartbeat de LED para operação normal
2026-07-21 Adiciona alarme diário com controle via USB e botões locais
    Implementa a funcionalidade de alarme diário, configurável tanto pela aplicação Python no PC quanto por dois botões físicos no aparelho.
    - **Alarme:** O horário e a habilitação do alarme são persistentes, armazenados nos registradores do DS3231 (alimentados pela bateria), contornando a ausência de EEPROM no PIC16C745. Um buzzer (RC2) fornece aviso sonoro intermitente, com auto-silenciamento após dois minutos.
    - **Controle:**
    - O utilitário `dtc_sync.py` ganha opções para programar, ligar e desligar o alarme, além de exibir o estado completo do relógio (`--status`).
    - Dois botões (RA0, RA1) permitem alter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
    [ds3231.c, main.c, uart.c]
2026-07-21 ```
    Melhora robustez do display VFD e integra LED de heartbeat permanente
    Este commit aprimora a confiabilidade do sistema e a experiência do usuário com as seguintes mudanças:
    - **Display VFD:**
    - Corrige a perda de caracteres após comandos de posicionamento adicionando atrasos de "respiro" (`VFD_ATRASO_POS_MS`), essenciais para a confiabilidade da comunicação serial com o VFD.
    - Impede a rolagem vertical indesejada do display ao ativar o comando `Scroll Line Lock`, garantindo que o conteúdo de cada linha permaneça fixo.
    - Implementa um mecanismo de refresco periódico (a cada 15 minutos) que reafirma o estado do display (cursor invisível, home) e força um redesenho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
    [main.c, uart.c, vfd.c]
2026-07-21 Atualiza .gitignore para ignorar backups do Proteus em qualquer nível
    Ajusta a regra de ignorar a pasta "Project Backups/" do Proteus para que ela
    seja aplicada em qualquer diretório do projeto, não apenas em HARDWARE/.
    Isso garante que todas as pastas de backup geradas pela ferramenta sejam
    devidamente ignoradas, independentemente da subpasta onde se encontram.
2026-07-22 feat: Implementa menu de configuração, persistência de brilho e aprimora UX
    Este commit introduz um menu de configuração interativo, adiciona persistência para o brilho do display e refina significativamente a experiência do usuário e a robustez do sistema:
    - **Interface e Configuração:**
    - Adiciona um menu de configuração acessível via botões para gerenciar o alarme e o brilho da tela.
    - O nível de brilho do display agora é persistido nos registradores do Alarme 2 do DS3231 (atuando como uma EEPROM virtual), mantendo a configuração após desligamentos.
    - O novo script `configurar.bat` para Windows oferece uma interface amigável por menu, incluindo verificaç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
    [Config_1.txt, Config_2.txt, VFD_AUX.dxf]
2026-07-22 hw: divide em 4 placas e realoca DS3231 (I2C em RB4/RB5, INT/SQW em RB0)
    - firmware: SDA->RB5 (26), SCL->RB4 (25), INT/SQW->RB0/INT (21, uso futuro);
    ajusta board.h, main.c e swi2c.h (mascaras e TRISB)
    - docs: pinagem.md e README.md refletindo a nova pinagem
    - hardware: projetos Proteus das placas do VFD e de botoes
    (AUXVFDBOARD, AUXBOTBOARD) + PDFs
    - chore: remove backups do Proteus do rastreamento (ja cobertos pelo .gitignore)
2026-08-16 feat: Adiciona sincronização de hora via NTP (internet)
    Implementa a opção de sincronizar o relógio VFD com a hora oficial da internet usando NTP, oferecendo precisão superior à hora do PC.
    - **Precisão:** Utiliza o protocolo SNTP (RFC 4330) para obter a hora com acurácia de milissegundos, medindo e descontando o tempo de trânsito da rede.
    - **Independência:** Não adiciona novas dependências ao Python, usando apenas `socket` e `struct` da biblioteca padrão.
    - **Servidores:** Consulta `a.ntp.br`, `b.ntp.br` (NTP.br) e `pool.ntp.org` (reserva), com opção de `--ntp-servidor` customizado.
    - **UX:** Integrado como opção recomendada no `configurar.bat` para Windows e adicionado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
2026-08-17 hw: Adiciona PDF da placa principal VFD_CLOCK e atualiza arquivos de hardware
    - Adiciona o esquema/layout em PDF para a placa principal VFD_CLOCK.
    - Atualiza os PDFs das placas auxiliares (AUXBOTBOARD e AUXVFDBOARD).
    - Atualiza o arquivo de projeto Proteus (`VFD_CLOCK.pdsprj`).
2026-08-17 feat: Alarme por dia util e indicador de alarme na tela
    Alarme em tres estados (desligado / todos os dias / so dias uteis),
    escolhidos ciclando o botao 2 sobre a opcao ALARME do menu.
    O modo e guardado no registrador 0Dh do DS3231 - o terceiro do Alarme 2,
    que o projeto nunca habilita (A2IE fica em 0). A area de configuracao
    passa a ser 0Bh (brilho) + 0Ch (validade) + 0Dh (modo), gravada numa
    transacao so, sem tocar no A1IE nem no horario do alarme.
    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
2026-08-18 hw: Adiciona projeto ELNEC e atualiza projeto Proteus do VFD Clock
    - Adiciona o arquivo de projeto do programador ELNEC (`elnecproj.eprj`).
    - Atualiza o arquivo de projeto Proteus principal (`VFD_CLOCK.pdsprj`).
2026-08-18 NÃO FUNCIONA Prevents stack overflow by redefining UDC function as macro
    Refactors the User Defined Character (UDC) definition from a function to a
    macro to avoid implicit stack usage on PIC16 midrange microcontrollers.
    The previous `vfd_definir_udc` function, when reading `const uint8_t` arrays
    (which become `RETLW` tables in PIC16 program memory), generated an invisible
    `CALL` instruction within its loop. This consumed two stack levels: one for
    the function call itself, and another for the `RETLW` table lookup.
    Combined with the 4 stack levels used by the USB ISR, this exceeded the PIC16's
    8-level hardware stack, causing an unrecoverable crash during boot (when
    `vfd_iniciar` is called).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
    [main.c, vfd.c]
2026-08-18 fix: Volta ao estado funcional e traz so o novo layout de tela
    O commit 96c1eb8 nao roda no PIC16C745 (display mudo, sem heartbeat).
    A bisseccao mostrou que o layout de tela nao tem culpa: este build,
    gravado e testado no hardware, funciona.
    Reverte para o conteudo validado de bc45239 os arquivos vfd.c, vfd.h,
    ds3231.c e ds3231.h (byte a byte), e mantem em main.c apenas a mudanca
    de layout:
    - linha de cima passa a ser SEMPRE o relogio, na mesma posicao;
    - linha de baixo alterna no carrossel de sempre (6 s data / 4 s clima);
    - clima vira "23.4 C 45.2 %RH", com espaco entre numero e unidade;
    - tela_hora + tela_clima viram tela_principal(completo, inferior).
    Como a hora ficou fix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
    [ds3231.c, main.c, vfd.c]
2026-08-19 fix: Corrige estouro da pilha de hardware e liga o watchdog
    Gravado e testado no hardware: o relogio roda estavel pela primeira vez
    desde a introducao do novo layout.
    CAUSA RAIZ. O relatorio do XC8 mostrava "_main: Hardware stack levels
    required when called: 8" e "_usb_isr: 3". O PIC16C745 tem 8 niveis de
    pilha de HARDWARE e ela e CIRCULAR, sem detecao de estouro: quando a
    ISR do USB entrava no ponto mais fundo do laco, sobrescrevia o endereco
    de retorno mais antigo e o PIC voltava para lixo. Nao travava com erro,
    sumia. Como depende do instante em que a interrupcao cai, o defeito era
    uma CORRIDA -- por isso builds quase identicos ora rodavam ora morriam,
    e por isso a versao instrumentada (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
    [main.c, vfd.c]
2026-08-19 feat: Restaura o sino e alinha a documentacao com o firmware
    Validado no hardware: o conjunto completo roda estavel.
    SINO. Volta a implementacao de eba5cc2 -- funcao com array `const`, o
    mesmo laco lendo udc_sino[i] e os mesmos dois __delay_ms. E, byte a
    byte, o codigo que ja funcionou aqui e que funciona no projeto do
    PIC18F2550 com ESTE MESMO display.
    A tentativa anterior de transforma-la em MACRO com literais imediatos
    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
